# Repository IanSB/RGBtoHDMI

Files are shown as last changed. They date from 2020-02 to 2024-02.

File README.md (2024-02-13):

# RGBtoHDMI

The RGBtoHDMI interface converts the "digital" RGB video signal from
the BBC Micro or Electron to HDMI compatible with most modern
TV/Monitors. The interface comprises a Raspberry Pi Zero and a
specially designed Hat containing a small CPLD. Custom firmware on the
Raspberry Pi, in conjunction with the CPLD, is able to correctly
sample each of the Beeb's video modes to give a pixel-perfect
rendition.

For more information, see the project [Wiki](../../wiki).  
Assembled boards available here:  
https://github.com/IanSB/RGBtoHDMI/wiki/Assembled-boards-for-sale

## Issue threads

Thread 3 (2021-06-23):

amiga hoglet, software rgb/hdmi

c1581, 2021-06-23:
First time on Github, so forgive me if this is not the correct way to ask a question.

I have the rgm/hdmi adapter, commodore amiga 500, with an ACA500 plus.   Installed the adapter, on Pi0 checking for proper orientation,  software on SD card is:  20210529_777ea4f Release.

I get the "four color screen",  Amiga boots to the aca500 menu..   I get a blank screen, unless I press the spacebar, then I get a picture..  Booting, into the Amiga, screen goes blank and stays blank..   Removing the aca500 card, and just booting the amiga "plain", with 1.3 or 3.1 and again, just get a blank screen.

Is there some configuration I am missing?   I've tried it with two different Pi0's,  two different  Tv's

Thank you.

IanSB, 2021-06-28:
Which type of RGBtoHDMI board are you using?
Can you call up the RGBtoHDMI menus?

c1581, 2021-06-28:
I figured it out. I wasn’t getting any menus or anything. I soldered momentary push button on it and was able to determine it was the hertz setting. Increased from 50 to 60 and it was fine.

Thank you for getting back to me

Sean

Sent with [ProtonMail](https://protonmail.com/) Secure Email.

‐‐‐‐‐‐‐ Original Message ‐‐‐‐‐‐‐
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

Closed 2021-06-30.

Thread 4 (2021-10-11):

BOM Atari 12bit buffered pickup

md66pt, 2021-10-11:
Hi, first I want to thank you very much for your great work! I love this project and already have built one for C64 and Amiga 500.

Please let me ask you, if there is a BOM for the Atari ST 12bit unbuffered pickup board? I see two ic's and two caps at the gerbers.

I am restoring a 1040 STFM right now and would like to build one for it!

Thanks in advance, regards Wolfgang.

md66pt, 2021-10-17:
Sorry, found it in the Atari ST discussion #6!

mikrosk, 2022-03-05:
Just for future reference, he meant https://github.com/c0pperdragon/Amiga-Digital-Video/issues/6

Closed 2021-10-17.

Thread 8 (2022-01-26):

Atari MegaSTE issue

Biker1bob, 2022-01-26:
I have built one of the devices up with a 12bit board I purchased assembled - its an IanSB board.

This is the topic thread I am getting my info from https://www.atari-forum.com/viewtopic.php?t=40201

My situation is - in LOW or MEDIUM resolution - where I would use the RGB colour (AKA NOT MONO) Green is substituted for Black - I cannot get the device to produce a BLACK - It is using the STE 50hz profile. My monitor is able to do 50hz. EVERYTHING else looks fine except where a black should be there is Green.

I have adjust every setting in the software I can think of. I have rechecked all my wiring 10+ times.. I am at a loss. Any suggestions would be appreciated

I have posted this in the main Github for the project. - just thought I would post here as well incase some only follow this fork.
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

IanSB, 2022-01-28:
Addressed here:

https://github.com/hoglet67/RGBtoHDMI/issues/268

Closed 2022-01-28.

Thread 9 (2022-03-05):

Is the buffer board needed only on the Atari ST?

mikrosk, 2022-03-05:
After reading this: https://github.com/c0pperdragon/Amiga-Digital-Video/issues/6#issuecomment-766461800 and this: https://github.com/c0pperdragon/Amiga-Digital-Video/issues/56#issuecomment-933144980 it would seem that STE models do not really require this board? Not that it would be easily possible to install it (DIP vs QFP package of later Shifter models) but still it makes me wondering whether ST signal is really that bad and much improved in STE models?

IanSB, 2022-03-08:
No, the buffer board isn't needed in the STE. It isn't really needed in the ST either as you can solder directly from the 12 bit extender cable to the shifter pins but it does make fitting it easier as the upgrade is mostly plugin. I added the buffer chips to try to protect the shifter from any damage (e.g. static discharge through the cable) and they aren't really needed for signal quality reasons.

mikrosk, 2022-03-08:
Thanks. While we are on the topic, where do the three wires go?

IanSB, 2022-03-08:
They are HSYNC, VSYNC and BLANK and they are available on the Glue chip, details in the "Atari ST 40 pin shifter" section of the cables guide in the wiki:
https://github.com/IanSB/RGBtoHDMI/wiki/Cables
The H&VSYNC signals are also available on the modulator header (be careful when connecting as there is also 12V on that header) and the BLANK signal is also available on diodes around the shifter chip but the actual component numbers differ depending on the ST variant so you will need to check the schematic.

mikrosk, 2022-03-08:
Much appreciated, @IanSB.

Closed 2022-03-08.

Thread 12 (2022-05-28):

Atari STE - 9-bit adopted from STE (12-bit will come using Amiga pickup)

luciust, 2022-05-28:
Hi, thanks to @IanSB guidence - I've adopted temprorary Atari ST pickup board intended for Shifter (40-pin) to Atari STE.
The process requirer soldering and will only use 9-bits - not 12-bits, but thanks to the pickup board and bus transcievers - it makes your Atari STE safe from electrical mishaps.
Closeup of the actuall solders:

(Yellow cable is MONO)
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
HSYNC - right pin & VSYNC on left pin):
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

Results:
Mono is of course perfect:
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
Colour - it has some tint - i.e. white has cyan tint, red is a bit wahsed out, but it's far beter then expected:
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

Let me know if this need more explenation in meantime - I'm waiting for Amiga pickup that will add the 12-bit mode. Also - soldering will always be required, as the clearance for the signals pickup is HARD - my STE has PSU on top of it.

luciust, 2022-06-12:
@IanSB
So I've used the Amiga 12-bit pickup board, tested color modes:
- The HSYNC and VSYNC signals have been replaced by Composite Sync from PIN 2 of MC1377 (Color Television RGB to PAL/NTSC Encoder) which is sitting before modulator
- using your 12 bit adapter for RGB2HDMI issue 2
- Mono signal has been attached to PIN of U3 as suggested by you and the chips leg is lifted
- Beta54 FW and STE profile
- RPi Zero and Zero W (testing on two different units)

The outcome:

- in game menu - the picture is exactly *the same* as with 9-bit signals (0-2 mode) which I tested before - it's darker than original - with colors close to real output - but the colors are completly screwed (dakr green is pink and so on!) - but just during the actual game of Lotus (STE version) - blitter is running then.
- in GEM mode, the while is now white (without cyan tint) and the colors in the GEM menu are OK, but only first 8, where the next 8 are same color as 8 before. On regular monitor - the next 8 colors are lighter - which coresponds with above "darker" picture.

Other:
Minimal color artefacts are visible on some of the parts of picture,

Wondering what might be the issue?

IanSB, 2022-06-13:
First check that the sampling menu is set to 12bits per pixel with the STE profile.
Then check that the bits are in the right order
i.e. G3 on STE is connected to G3 on the Amiga pickup board, G2 <> G2, G1<> G1, G0<>G0 etc same for red & blue

IanSB, 2022-06-13:
Also need to check your soldering for shorts or unconnected pins

IanSB, 2022-06-13:
>I still haven't double-checked if my info on the R-G-B signals is correct and correctly wired - so that is still to do

That seems to be the likely cause. If the STE is anything like the ST you need to get the exact schematic for your motherboard because the different revisions of the ST all had different numbering for the resistors so using someone else's info might not work.

The grn1/VS pin will have the mono signal in mono mode but should be inactive in colour modes.

Is there a test pattern program for the STE?
On the Amiga I use the "Amiga Test Kit" and that displays ramps of RGB which makes it immediately obvious which bits are wrong:
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

luciust, 2022-06-14:
@IanSB The actual board - the MONO hack uses unused socket to meet the patch with mono signal (white cable), the purple is the CSYNC, and R G B are of course RGBs...
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

IanSB, 2022-06-14:
@luciust

>Thanks to Lopez from local Discord (greetz!) I got the gray tester.
>Look - the 1-3 or 12-bits are the same wrong. But the mode 0-2 is nearly OK, look:

That confirms that you have all the bits rotated by 1
Note that the ST (not STE) is unusual in that you connect the high source bits to R2, G2, B2 and leave R3, G3, B3 used for other things (hence "9 bits (bits 0-2)").
The STE has the more standard connections where the highest bits go to R3,G3,B3.
The STE should look correct when using "9 bits (bits 1-3)" and wrong when using "9 bits (bits 0-2)" but your results are the other way around, hence you have connected STE RGB3 to input RGB2, STE RGB2 to input RGB1 and STE RGB1 to input RGB0.
When you enable full 12 bits per pixel you get alternate dark and light stripes because STE RGB0 is connected to input RGB3 (the brightest part of the signal which alternates on/off with every bar)

So you need to rotate all your RGB connections by 1

luciust, 2022-06-14:
@IanSB
That seems to be right, and there's another issue in the C0pperDragon forum.

That also means that the STE Shifter datasheet I got is probably wrong.

Anyway, when I get back I hope to nail it finally, and when sucessfull I'll share the details in FAQ - since I've broken pretty much everything by noe, and found 4 different data on the R,G,B signals :)

Thanks for patience!

luciust, 2022-06-14:
For reference: this is the GST Shifter "datasheet" I've been checking my signals with:
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

luciust, 2022-06-15:
Finally - it works!

Based on your suggestions and pixelk0 schema - it works very well:
https://user-images.githubusercontent.com/5732483/124193866-e2011180-dac7-11eb-95ec-914855c7fa58.jpg

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

IanSB, 2022-06-15:
@luciust

Does mono mode work as well?

IanSB, 2022-06-16:
The genlock is inhibited by default in mono mode because some monitors can't lock above 60Hz and mono mode is 71 Hz. Inhibiting the genlock forces the HDMI output to 60Hz which means you should always get an image on the screen.
If your monitor can lock to 71Hz you can try changing the refresh to "Force 50Hz-Any" which should allow the HDMI output to always track the frequency of the input.
Use menu+reset to recover if this doesn't work.

luciust, 2022-06-16:
Good idea, I got two more make-SHIFT HDMI monitors - fun thing to try!

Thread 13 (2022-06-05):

Amiga 500 -colors are displayed incorrectly | black is dark red

sascha70, 2022-06-05:
Hello community,

unfortunately a bug is driving me crazy with the Amiga 500.

Unfortunately, the colors are displayed somewhat incorrectly for me. What should be black is dark red. I used the Beta54 version from JanBeta and the version from main tree 20211224_c97f06a release. All have the same problem. The adapter is from LinuxJedi (https://github.com/LinuxJedi/AmigaRGBtoHDMI/tree/main/Amiga500CPLD).

Do you have a solution?

Thanks

sascha
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
a

solarmon, 2022-06-05:
Looks like one of the red signal is missing or shorted together? I would inspect and check the soldering of the red signals and traces on the adapter itself.

Did you build the adapter yourself?

sascha70, 2022-06-05:
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

They were right. It was the plug-in lead from the Pi Zero. I checked it with a Pi 3 A+ and it worked great.

Thanks for your great project!

Greetings

Sascha

Closed 2022-12-21.

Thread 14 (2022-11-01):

Apple IIc colors inverted/wrong with Beta54

jma7x, 2022-11-01:
I just tried Beta54 with my Apple IIc (TTL interface) with a Pi 3 B, and the colors are somehow inverted/wrong.
I see the Artifact Type defaults to "Apple (Zero 2W)".  If I change it to "Simple (Old Code)", then it seems fine.
This affects both text and graphics.  (Note: I also tried Beta53 and it seemed to only have the issue with graphics)

So I guess the question is, should the new artifact color work with the Pi 3 B (from the release notes, it sounds like it?)

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

Thanks

IanSB, 2022-11-05:
@jma7x

It looks like the new artifact code can't handle the inverted video on the IIc's digital output. I don't have a IIc but I can pick up the same signals internally on the IIe so I will have a look at that when I have made up a lead.
The new code should work on the analog video output which is not inverted but would require an analog board.

jma7x, 2022-11-06:
Unfortunately I don't have an analog board, so I can't try that.  I can test any updates you make though for the digital output if that would help.
Would it be feasible to just have the cpld invert the signal?

IanSB, 2022-11-06:
@jma7x
>Would it be feasible to just have the cpld invert the signal?

No, the fix would have to be be done in software.

IanSB, 2022-11-26:
@jma7x

FYI I've just made up a lead so there should be a fix soon now that I can test it

IanSB, 2022-11-28:
@jma7x

There is a new beta 55 with a fix for Apple IIc colors here:
https://github.com/IanSB/RGBtoHDMI/releases

Let me know if it works for you

jma7x, 2022-11-29:
Looks good with beta 55!
Switching back and forth between the old code and the new, solid blocks of color seem the same, but I do see the subtle improvements on edges with the new code.
Thanks!

IanSB, 2022-11-29:
@jma7x
>Looks good with beta 55!
Switching back and forth between the old code and the new, solid blocks of color seem the same, but I do see the subtle improvements on edges with the new code.

Thanks for confirming.
The new code is mainly meant for CGA sources as it works properly in 320x200 4 colour modes and also displays the >1000 colours generated by the 8088mph demo. The old code only works in mono mode mode on CGA (i.e. similar to the Apple II) and displays a maximum of 16 colours.

Closed 2022-11-29.

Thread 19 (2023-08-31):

Alpha 60

IanSB, 2023-08-31:
Alpha 60A

Allow Apple 4 line mono to work with non-inverted video:
[Alpha60A.zip](https://github.com/IanSB/RGBtoHDMI/files/12491134/Alpha60A.zip)

IanSB, 2023-10-12:
Alpha 60B

Add Atari 2600 lumacode support
Use clock tolerance to determine lines per frame window
Fix scanlines not working on Atari 800
Some profile updates

[Alpha60B.zip](https://github.com/IanSB/RGBtoHDMI/files/12887405/Alpha60B.zip)

Closed 2023-10-14.

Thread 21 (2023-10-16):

Alpha61

IanSB, 2023-10-16:
Alpha 61A

This has a major new feature, a "Create Custom Profile" menu which makes it a lot easier to create profiles for unsupported computers.

There is some documentation on how to use it in the Info menu:

[Alpha61A.zip](https://github.com/IanSB/RGBtoHDMI/files/12922481/Alpha61A.zip)

IanSB, 2023-10-19:
Alpha 61B

Fix some issues with Profile Creation when using lumacode

Add PAL artifacts to c0pperdragon Commodore 64 YUV interface profile

[Alpha61B.zip](https://github.com/IanSB/RGBtoHDMI/files/13035203/Alpha61B.zip)

IanSB, 2023-10-19:
Alpha 61C

Add variable level scanlines to Atari 800 lumacode

[Alpha61C.zip](https://github.com/IanSB/RGBtoHDMI/files/13043471/Alpha61C.zip)

IanSB, 2023-10-22:
Alpha 61D

Updated Profile creation menu with some fixes and additional help:

[Alpha61D.zip](https://github.com/IanSB/RGBtoHDMI/files/13064442/Alpha61D.zip)

IanSB, 2023-10-26:
Alpha 61E

Add automatic detection of HDMI mode (DVI monitor or HDMI monitor)
Note the manual HDMI mode setting has now been moved to the Settings menu

Measure vsync width when calculating capture size (many Atari 2600 games have non standard vsync width)

Update Atari 2600 profile

[Alpha61E.zip](https://github.com/IanSB/RGBtoHDMI/files/13181117/Alpha61E.zip)

IanSB, 2023-11-06:
Alpha 61F

Add 4K @50/60Hz for Pi 4 (This mode is auto detected and selected on a Pi 4)
Note when connected to a 4K monitor with other Pi models, 1080p is auto detected as they can only display 4K @ 25/30Hz
You can manually select this mode if required.

Update VIC20 palette

[Alpha61F.zip](https://github.com/IanSB/RGBtoHDMI/files/13261487/Alpha61F.zip)

IanSB, 2023-11-08:
Alpha 61G
Add 'Film Mode' to drop every other frame for 25/30Hz operation
Only prevent palette dimming for brt/cont/sat/gamma/tint

[Alpha61G.zip](https://github.com/IanSB/RGBtoHDMI/files/13301831/Alpha61G.zip)

IanSB, 2023-11-09:
[kernelrpi-capturefix.zip](https://github.com/IanSB/RGBtoHDMI/files/13303587/kernelrpi-capturefix.zip)

IanSB, 2023-11-11:
[kernel_test.zip](https://github.com/IanSB/RGBtoHDMI/files/13324145/kernel_test.zip)

Closed 2023-11-12.

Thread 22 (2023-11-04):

Artifact Colors with Atari 800 Lumacode ProfIle

scorpio-ny, 2023-11-04:
Hi @IanSB ,

I have enabled artifact colors to use with some games that use color artifacts with the Atari 800 Lumacode profile. I am using the latest beta firmware. When I turn it on artifacting in the palette menu and try to set the colors be switching the angles, nothing seems to happen. Is there something else I need to do?

IanSB, 2023-11-04:
@scorpio-ny

Artifacting is not yet supported on the Atari 800.
Currently NTSC artifacting is supported on mono (e.g Apple II / Tandy CoCo) and CGA (IBM PC)
PAL artifacting is supported on 16 colour lumacode profiles such as the Commodore 64

What Atari 800 programs use artifacting?

scorpio-ny, 2023-11-05:
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

Hi @IanSB ,

Quite a few games used them since a lot of them were ports from the Apple II back in the day. Here is a partial list:
Ultima II, Ultima III & Ultima iV
Flight Simulator II
Drelbs
Pinball Contuction Set
Choplifter
LodeRunner
Snakebyte
Wavy Navy
Night Mission Pinball
Hard Hat Mack
A.E.
Threshold
Lunar Leeper
Aztec

IanSB, 2023-11-06:
@scorpio-ny

Are these games all in mono like an Apple II or do they mix the mono with other colours?

scorpio-ny, 2023-11-07:
> @scorpio-ny
>
> Are these games all in mono like an Apple II or do they mix the mono with other colours?

A little of both. Most of the examples I linked are mono like the Apple II. The Atari can also split the graphics modes on the screen  so part of the screen is mono and the rest has color. On the mono graphics modes games, the color are all generated by artifacts. What is interesting about the Atari is depending if it had the CTIA or GTIA chip or the model of Atari computer, the artifact colors it creates can be different.

Here is a link to an article on the subject that hopefully provides some useful information:
http://www.atarimania.com/faq-atari-400-800-xl-xe-what-is-artifacting_22.html

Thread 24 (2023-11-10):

NTSC Atari 800XL with PAL Antic

smarquette, 2023-11-10:
I have a NTSC Atari 800xl with a PAL Antic and I’ve installed c0pperdragon’s GTIA digitizer for HDMI output. I can make it work with an NTSC Antic and GTIA, but if I switch the Antic to PAL, I can’t find a setting that will make this work.

IanSB, 2023-11-10:
@smarquette

I assume this means you would be outputting PAL frame rate but with the timing derived from an NTSC crystal?
Does the resulting PAL timing produce colours with the NTSC palette or the PAL palette?
To support such hybrid modes would need a couple of extra profiles in the Atari folder, the settings of which depend on the above answers.

smarquette, 2023-11-10:
Yes with NTSC crystal. Color palette is NTSC and I have a Ultimate 1MB upgrade that can force the NTSC colors. I have a few newer games that need to see PAL Antic. Thanks!
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

IanSB, 2023-11-10:
@smarquette

Delete the profiles folder on the SD card and unzip then replace with this one (reboot the Pi):

[Updated_Profiles.zip](https://github.com/IanSB/RGBtoHDMI/files/13323521/Updated_Profiles.zip)

This should support the following hybrid combinations but is untested:

NTSC GTIA with NTSC crystal and PAL Antic
PAL GTIA with PAL crystal and NTSC Antic

Let me know if this works and I'll include it in the next beta due soon.

smarquette, 2023-11-10:
Thanks Ian,
I'll give it a try tomorrow.
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

smarquette, 2023-11-11:
Doesn't seem to work, I've tried all the Atari 800 lumacode profiles. Here's a picture of the screen.

Thanks
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

IanSB, 2023-11-11:
@smarquette
>Here's a picture of the screen.

Images don't seem to be included if you reply by email, I think you have to post on the github thread instead.

Can you also post a copy of the source summary page in the info menu. You can screencap this by pressing the up and down buttons (file on SD card in  /captures)

smarquette, 2023-11-11:
OK Here are the pictures:

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

IanSB, 2023-11-11:
OK it looks like the new profile will only work with the latest alpha versions so try this version:

[Alpha61H-with-new-profiles.zip](https://github.com/IanSB/RGBtoHDMI/files/13325827/Alpha61H-with-new-profiles.zip)

IanSB, 2023-11-11:
@smarquette
Do a clean reinstall of the above  by wiping the SD card and then re-select the Atari profile

smarquette, 2023-11-11:
Seems to be working.
Thanks!!!

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

IanSB, 2023-11-11:
@smarquette
>Seems to be working.

Thanks for confirming, those profiles will be in the next official beta (Beta 61) which will be released in the next day or so

A couple of questions:
What is the physical resolution and size of your monitor? (It looks similar to some 10" 1024x768 monitors I have)
In the above screenshots it shows resolution set to "Auto" but in the summary menu it shows Pi resolution set to 720x480 which is not a standard LCD resolution as far as I'm aware.

Could you use the save log.txt and EDID.bin option in the source summary menu and post those two files from your sd card.

Also do some PAL Atari games use more than 200 active lines (i.e. more active lines than an NTSC equivalent)?

smarquette, 2023-11-11:
The monitor is a 12” HD TV that can do NTSC and PAL. Since the last screenshot, I’ve changed the resolution to 1280x720 and the monitor reports it as 720p. 60hz.
If I connect my PAL C64 to my RetroTink 2x it displays as 576p.

I’ll upload those menu screen captures when I get back tomorrow morning.

As for the PAL games, I have a few, but I’m not sure of number of lines. The only game that wont run on a NTSC Antic is Bubble Shooter. The others just run at a slightly faster speed. The NTSC games all run at a slightly slower speed that is hardly perceptible.
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

IanSB, 2023-11-12:
@smarquette
I found this monitor on Ali Express:
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
Is that it? It's available in 800x600 and 1024x768 resolutions

If so you should try setting the resolution to the correct one of those two. One will look extremely sharp, the other will have softer edges.
RGBtoHDMI produces the sharpest results when set to the native physical resolution of the monitor but in that integer scaling mode some combinations of computer resolution and monitor resolution will produce larger borders. In this case 800x600 will have larger borders than 1024x768 so the latter will give the better results if your monitor is also 1024x786.

smarquette, 2023-11-12:
That looks just like it. I got it on Amazon a few years ago. I’ll give changing the resolutions a try and see if it improves.

smarquette, 2023-11-12:
Here are the log files you requested.

[logfiles.zip](https://github.com/IanSB/RGBtoHDMI/files/13328148/logfiles.zip)

This version of the monitor is actually a TV and can do up to 1920x1080 (1080p) resolution as well as standard computer resolutions.

I'd like to find a resolution/scaling setting that will fill most of the screen. Right now there is just a box in the middle with a 2-3cm border. I can use the zoom menu in the TV's menu to fill most, but it doesn't retain the setting when I turn it off.

Thanks again.

IanSB, 2023-11-12:
@smarquette
>Here are the log files you requested.

Thanks, the monitor is detected as 800x600 physical resolution so that should be the resolution selected when set to auto:
```
Timing descriptor detected as 800x600
```
Is that the case?

>This version of the monitor is actually a TV and can do up to 1920x1080 (1080p) resolution as well as standard computer resolutions.

It will probably accept a large range of resolutions and then scale them (interpolate) to fit the 800x600 screen

>I'd like to find a resolution/scaling setting that will fill most of the screen. Right now there is just a box in the middle with a 2-3cm border.

Yes, that is the problem with such a low resolution monitor, because there are so few pixels the computer resolution doesn't fit nicely into the screen resolution for integer scaling (where one computer pixel is mapped to an exact number of LCD pixels) so you end up with larger borders. This is less of a problem with higher resolution screens like 1920x1080.
See the opening page of the wiki for the difference between integer and interpolated scaling:
https://github.com/IanSB/RGBtoHDMI/wiki

To fill the screen you would have to change the scaling setting to Interpolate 4:3/Soft in the main menu and then use the crop border (zoom) setting in the preferences menu to crop off as much of the border as you prefer (use save configuration to save that setting)
When using interpolated scaling you can change the aspect ratio a little by altering  the Max Height and Max Width settings. Again use save configuration to save that setting

You may get better results by changing the scaling setting to Interpolate Full/Soft and trying all the other resolutions including widescreen ones (followed by the crop border (zoom) setting if required) as they may get squashed to fill your 4:3 screen.

BTW there is now a new beta 61 official release with the hybrid Antic support:
https://github.com/IanSB/RGBtoHDMI/releases

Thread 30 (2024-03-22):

Unable to see new profiles on the profile menu.

Finklewart, 2024-03-22:
Hi,
I've created a custom profile and can use it fine loaded as custom profile 1.
I followed the instructions on the wiki to move it to the normal profile folders and renamed it to a sensible name but whatever i do i can't get it to show up on the normal profile menu.
I'm sure I'm doing something silly.
I've got the correct 6-12_BIT_YUV_Analog folder and ive not renamed the extension from .txt
I notice a lot of the folder and file names are using _ instead of space but i tried folder and file names without spaces and that didn't work either.

Many thanks,

Jim

IanSB, 2024-03-23:
@Finklewart
What RGBtoHDMI board are you using? (i.e. main CPLD + analog board or the special lumacode/mono board)
If it's the lumacode/mono board then you need to add a trailing _ to the filename before .txt to make it show up in the profile lists. plus any new machine name folder (like Commodore / Apple etc) also has to have a trailing _

So if your machine name was Foo and the profile was Bar.txt then you need to create a folder:
/Profiles/6-12_BIT_YUV_Analog/Foo_/Bar_.txt

The reason is that both the analog board and the lumacode board share the same profile folder but only a subset of those profiles will work on the luma board so to avoid confusion profiles that don't work (i.e. without the trailing_ ) are hidden.

Leading _ is also used to change the sorting of files and folders so that special folders like Test and Custom appear at the end of the list and not in between normal manufacturers.

All the _ characters are removed or replaced by spaces in the menus so this is normally hidden from the user.

BTW what is your custom profile for?
If it's an unsupported machine perhaps you would post it here for inclusion in a future release.

Finklewart, 2024-03-23:
Hi, thank you for your reply.
It's just using the analog board, the same one as used on the ZX80/81/Apple/UK101/Ohio etc.

So for the normal analog board i don't need to worry about the trailing _ ?

The machine is a 911VDT card in a Texas Instruments TI-990 system, it has a composite video output.
Once I can get it to appear in the menu correctly i will post it.

IanSB, 2024-03-23:
@Finklewart
If it's the normal analog+cpld board pair with the 6 way IDC connector then it shouldn't need the trailing _

What is the exact path + filename you are using?

Finklewart, 2024-03-23:
Hi,
The analog board i have has a single 3.5" connector.
Is that the lumacode board ?, the person i bought it from didn't mention lumacode.
Ah, i've added the trailing _ to the path and the file name and it now shows up in the profile menu.
I had tried the _ on the file name and the folder name but i don't think on both at the same time.
Thank you very much.
I didn't see the mention of the _ in the tutorial for adding new profiles.

The file is attached, this is for the VDT911 board jumpered to 1920 characters (80x24) and 50 Hz, i will add the other 3 modes at a later date, 906 character (80 x 12 !) and both in 60 hz

Thanks for the help,

Jim

[Texas_Instruments_TI-990_VDT911_card_.zip](https://github.com/IanSB/RGBtoHDMI/files/14733354/Texas_Instruments_TI-990_VDT911_card_.zip)

IanSB, 2024-03-23:
@Finklewart
>The analog board i have has a single 3.5" connector.
>Is that the lumacode board ?

Yes. It's printed on the PCB and shown in the System Summary menu:
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

>The file is attached, this is for the VDT911 board

Thanks, it will probably appear in the "Other" folder for now.

>I will add the other 3 modes at a later date, 960 character (80 x 12 !) and both in 60 hz

It is best to create each profile individually but if the timing of these profiles is sufficiently different you can put them all in a sub-folder and RGBtoHDMI will auto select the correct one. This will certainly be the case for the 50/60 Hz ones but I don't know what difference there will be between the 80x24 and 80x12 ones. (There might not be any difference in which case both modes will work with the same profile)

See existing profiles for an example of the structure of this e.g:
/Profiles/6-12_BIT_YUV_Analog/Sinclair_/ZX81_Composite_

>I didn't see the mention of the _ in the tutorial for adding new profiles.

I haven't got around to documenting it so far. Actually, looking at the current profiles there are now a lot more uses of the _ than 'normal' profiles so it may be better to reverse the logic of this so the _ is used to signify the non-mono/luma profiles.
I might change that in a future release.

Finklewart, 2024-03-25:
Sorry for causing confusion, i'd not realised i was using the the lumacode version of the board.
Feel free to change the file and pathnames.
I think you are right, the 80 x 24 and 80 x 12 use the same screen resolution just with a lot more padding on the 80 x 12 characters.

Thanks agaon,

Jim

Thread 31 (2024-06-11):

Custom Profile (Osborne 1)

dadecoza, 2024-06-11:
I'm having an issue creating a custom profile,

According to the [Osborne 1 Technical Manual](https://www.esocop.org/docs/Osborne1TechnicalManual.pdf) the settings should be as follows ...

Width in pixels: 416
Height in pixels: 240
Dot clock: 8Mhz

However the output I get looks like ...

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

Any tips?

Thanks!

IanSB, 2024-06-12:
@dadecoza

According to the manual you linked, the actual crystal frequency is 15.9744Mhz:
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

So the "8" Mhz dot clock is 7987200 not 8000000 which might fix the mis-sampling but it looks like the image is shifted which can happen if the Hsync is wider than than the blanking period and not a normal hsync.
After tweaking the clock, can you post screencaps of the source summary page in the info menu and the geometry and sampling menus.
Press the Up and Down buttons together to screencap a menu, files in /captures on the SD card

IanSB, 2024-06-12:
@dadecoza

Looking at this further, the hsync signal is, as I suspected, not a proper hsync which usually lasts for 4.7uS and it is instead a square wave:
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
The profile is currently triggering off the edge in the middle of the screen so try changing the sync edge setting in the sampling menu which will make it trigger off the other edge.

dadecoza, 2024-06-12:
Progress!
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

Changing the edge to trailing fixed the alignment.

However it is still a little noisy.

IanSB, 2024-06-12:
@dadecoza

Have you tried adjusting the line length + or - 1, 2 or 3
(If the screen all goes noisy instead of clean on one of those settings that is probably the right value but you then have to run the calibration)

Also where have you connected the RGBtoHDMI inputs?

dadecoza, 2024-06-12:
I have tried playing with the line length but it did not help much. Not giving up though will mess around some more,

As for how it is connected ...

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

|  Osborne 1 | RGBtoHDMI |
|------------|-----------|
| VSync      | VSync     |
| HSync      | HSync     |
| Video Out  | Grn3      |
| Gnd        | Gnd       |

IanSB, 2024-06-12:
@dadecoza
The video output is really an analog signal which is at least one reason why the signal is noisy as you are feeding that into a digital input. Looking at the schematic:
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

The video is fed from a contrast control which will vary the voltage level and also the low intensity setting will reduce the voltage level too when active so characters with that attribute may appear noisy or blank.
Normally I would suggest using an analog interface addon but that can only use composite sync and in this case you can't easily combine the H and V sync signals with diodes to make composite sync because the Hsync signal is a very non-standard square wave.

It should be possible to modify an analog interface to inject separate syncs if you want to go that route but to get this working properly with the digital board you would have to connect internally to the inputs of those four open collector (O.C.) drivers shown above (Hsync, and Vsync with Grn3 and Grn2 connected to the video and intensity signals)

Turning up the contrast to max might help but the low intensity setting is still going to reduce the voltage level anyway.

dadecoza, 2024-06-12:
Hi Ian,

Thank you so much for your patience and detailed explanation.

As you probably gathered my knowledge of how video output work is very limited. At least I now have an explanation for the noise, and it really is not that bad,

Thanks again and feel free to close this ticket,

IanSB, 2024-06-12:
@dadecoza

Can you post your current profile.
Will either be in /Saved_profiles if you made any changes after creating your custom profile or if not then it will be in /Profiles

dadecoza, 2024-06-12:
[Custom_Profile_0_.txt](https://github.com/user-attachments/files/15806853/Custom_Profile_0_.txt)

as requested...

IanSB, 2024-06-12:
@dadecoza
There were some settings in your profile that needed tweaking:

As the hsync edge is so close to the active video that can cause problems so I switched from Leading to Leading+Delay (that also meant changing to 3bpp capture). Plus I set the pixel aspect ratio and the palette to mono.
It should still be possible to get this working with intensity although the connections might have to be different with a custom palette.

BTW the line length of 512 looks correct as it is a nice round binary number so all the noise is probably due to the analog signal.

Can you check that this profile is still OK and if so I will add it to future releases as it at least gets the timing correct so would be a good starting point for a fully correct profile:

[Osborne_1_(No_Intensity).txt](https://github.com/user-attachments/files/15807332/Osborne_1_.No_Intensity.txt)

Put it in this folder on the sd card:
```
\Profiles\6-12_BIT_RGB\_Other
```
reboot and select it from 'Other' in the profile menu

dadecoza, 2024-06-12:
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

Looking good!

dadecoza, 2024-06-12:
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

 Seems the intensity bit is more important than I thought ... In the above example the CP/M logo has a lower intensity and is completely absent from the RGBtoHDMI screen capture.

IanSB, 2024-06-12:
@dadecoza
>Seems the intensity bit is more important than I thought ... In the above example the CP/M logo has a lower intensity and is completely absent from the RGBtoHDMI screen capture.

There are several options to implement this:
1. Internal TTL connection
2. Use an RGBS analog addon board (some mods will be required to get the separate vsync in)
3. Use a mono/lumacode board. This is a board that contains the CPLD and part of the analog board, enough for multi level mono signals and it is mainly used with c0pperdragon's lumacode adapters to get RGBtoHDMI working with systems like the C64 / C128, Atari 800 & 2600, TI99 etc but it can be configured by using solder jumpers to input analog video and separate H and V syncs on a 3.5mm TRRS connector and that option was included for this kind of situation. (I have tried that on my Commodore PET.)
4. Use a couple of analog comparators on a breadboard between the Osborne 1 socket and the RGBtoHDMI to extract the two analog video levels. (This is effectively what the analog or mono/luma board does)

dadecoza, 2024-06-12:
Great thanks. :)

Our local vintage computing group is planning an "Osborne repair day" and I will then take the opportunity to try some of your suggestions. The repair day is also the reason I wanted to get the RGBtoHDMI working so that we can bench test/debug the main boards outside of the case.

dadecoza, 2024-06-12:
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

But man it still looks great!

dadecoza, 2024-06-12:
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
Amazing

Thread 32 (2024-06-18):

P6 on Lumacode Board?

venice1200, 2024-06-18:
This is not an issue!
I like to to know what function has P6 on the Lumacode Board.

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

Many Thanks

IanSB, 2024-06-19:
@venice1200

It's connected to the reset button for use with the hardware reset option on models other than the Pi zero.

For the Pi zero you can solder a 2 pin header on the zero board and a matching 2 pin socket in the two holes to the right of P6  (which is actually P4 on the underside) and that will allow the hardware reset option to work.

Other Pi models like the zero2W or Pi 1 to Pi 4 don't have the matching 2 pin header on the Pi board so you have to use a cable to link up from P6 to the reset input on those Pi boards (the location varies from model to model).

The lumacode board and the latest issue 7 normal CPLD board support software reset when the reset button is pressed so making the hardware reset mod is no longer essential and it's really only useful during software development to recover from crashed software when the software reset won't work.

venice1200, 2024-06-19:
Many Thanks for the information!

And all the best

Closed 2024-06-19.

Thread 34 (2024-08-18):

PAL Atari 65XE noisy video. Menu good.

sideburn, 2024-08-18:
I have a 65XE PAL and the video is noisy. Using most current firmware. Using Atari 800 lumacode (unterm) profile, and Atari 800 PAL palette.

Tried tweaking all settings I can think of but no luck.

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

video: http://sideburn.com/vid/lunacode.MOV

IanSB, 2024-09-11:
Atari noise issue answered in: https://github.com/c0pperdragon/LumaCode/issues/2#issuecomment-2295241781

Closed 2024-09-11.

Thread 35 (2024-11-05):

Atari STe - can a 12 bit extender support Mono and Colour?

shooking, 2024-11-05:
Hi there

fundamental question - should the RGBtoHDMI with 12 bit extender, suitably wired to an STe, allow low/medium colour and mono (shorting monitor 4 and 13)?

For my STFM I got it to work - had to modify profile on one system, worked with another "out of the box"

For my STe - colour worked when I chose the STe profile.
Mono - I get just a black screen, verified via screen capture, and grid lines with debug. But I see the analog out.
If I change sampling to 9 bits vsync I see signal partially getting thru

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

Hints appreciated. I am about to wire in just the 0v 5v, mono and csync as a test. BUT there seems to be a lot of debate regarding the RGB resistor ordering. See my notes at end.

Finally - would be great if WIKI showed pinout of the 16 pin male connector for the 12 bit extender.

MY SYSTEMS

So I have two types of RGBTOHDMI systems

1. RGBtoHD 12 bit issue 4 2018 - 20 Hoglet & IanB
2. RGBtoHD 12 bit issue 7 2018 - 23 Hoglet & IanB

And two 12 bit extenders

1. 12 bit adapter for RGBtoHD Issue 4 2022 IanB - struggled with STFM
2. 12 bit adapter for RGBtoHD Issue 2 2020 IanB - worked with STFM, colour STe but not mono

1. Atari STFM modified to 4Mb, CO78789
2. Atari STe CA 4003290 1989

and final part of "complication" I have

1. Pi Zero W V1.1 2017
2. Pi Zero 2 2021

WHAT WORKS

Atari ST worked with with a lot of help from Mikerochip and Javi.

I used shifter chip.
Issue 2 2020 adapter just worked.
Issue 4 2022 worked with colour. Needed help with mono
[reduce sample rate to 3bpp, modify palette to get b/w rather than yellow]
Pi choice was irrelevant (other than 1.1 allows reset)

I moved to the STe - and well things are a bit odd.

I can get colour but not mono.
Just a black screen.
Capture shows black.
Debug, show scanlines, show genlock ... displays something.
I feed the analog signal to a VGA monitor and the picture is clear.
The RGB is black BUT I modified AtariSTe Sampling to 9Bits Vsync and you can hopefully see the mono image in background. albeit geometry and position is off.

Any hints gratefully appreciated.

ONE HINT - would be nice to have a diagram of the IDC pins.
I believe they are "standard" but there is some ambiguity on the silkscreen. There is standard triangle with corresponding pin 1. But then 4 pins along there is P4. It _could_ mean ordering is Pin1 2 3 4 along long row. But seems to be normal pin 2 BELOW pin 1.
A diagram on the wiki would be cool.

I have researched and found official cable agrees with Mikerochip's hints

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

But I see other suggestions from pixelk - perhaps using an Amiga board?

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

Here's my comparison of these suggested resistors

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

And here's my photo (sorry I am red/green colour blind so I make it same as above chart BUT I am confused why there is a blu2, B2 then recommendations to change ordering due to STe R3 really being R0?
Could it be issue 4 fixes problem with issue 2 boards?

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

shooking, 2024-11-05:
I saw that thanks. I wasn't sure if the 12 bit extenders I got would work. If not (on the STe) I am OK with that - I will use MONO via VGA analog adaptor. All my monitors can handle it. I only have one monitor that could handle colour analog.

On your excellent write up I didn't understand the need to wire directly to chip. I will.re read.

I also don't understand why STFM works, but STe doesn't. I wonder if it is because the STE is using CSYNC rather than individual h and v.

luciust, 2024-11-05:
Actually - let me know which part was *not clear* - happy to change it if helps - primarly those are notes for me... So I don't have to remember it all.

CSYNC, or composite sync, can be described as a combined version of the HSYNC and VSYNC signals. Since CSYNC is defined by those two sub-components, and as you know HSYNC is horizontal sync and VSYNC is vertical sync and it is combined later for the RGBtoHDMI into CSYNC anyway. So - maybe you need to take a look at the STE profile? Show me your STE picture output and settings, maybe we will figure it out that way.

Definetly using the Amiga pickup solves any STE issues. Go for that! PCBs are very cheap today. I would send you one but it still would be more expensive than any 5 pcs from China.

shooking, 2024-11-05:
Hi and thanks.
What I am unclear about is if the 12 bit extender board I got can be modified to allow mono. My guess is the STFM version, using the level shifter and separate syncs, is doing something different to the STe.

I also see some discussion about R0 to 3 being labelled incorrectly on an STe.

I understand syncs. From what I read the STe profile knows a CSYNC will be passed in. This leaves the spare pin to interpret mono. I was hoping that the 12 bit extender I got would work in mono mode.

I will see if I can hack my setup and/or order Amiga PCB.

Thanks again

luciust, 2024-11-05:
I think it is correctly passing the MONO signal to the RGBtoHDMI sampler, but my mind is elswere now. It is hooked up to bus transciever and then... sorry - magic happens. I think the actual answer might be in my communcation couple of years back on this or on hoglet76 github, so if you can find my old posts - that would probably shed some light.

IanSB, 2024-11-05:
@shooking
>fundamental question - should the RGBtoHDMI with 12 bit extender, suitably wired to an STe, allow low/medium colour and mono (shorting monitor 4 and 13)?

Yes it should work with the mono signal fed to the Vsync input of RGBtoHDMI which is repurposed as a video input for mono mode. The mono sub profile should be auto selected when the sync signals switch to the higher refresh rate so confirm that the sub-profile shows as the mono one. (Auto selection is disabled when the menu is on screen so only call up the menu after switching)

>Hints appreciated. I am about to wire in just the 0v 5v, mono and csync as a test. BUT there seems to be a lot of debate regarding the RGB resistor ordering. See my notes at end.

The problem with bit ordering is due to the way that the STE schematic numbered the bits.

On RGBtoHDMI the bits were always R3, R2, R1, R0 ; G3, G2, G1, G0 ; B3, B2, B1, B0 with the '3' being the most significant bit  and '0' being the least significant bit.

On the ST there were only 3 bits each of RGB and they were numbered R2, R1, R0 and they could be mapped easily to the existing RGB inputs.

However on the STE an extra bit for each of RGB was added and this was the least significant bit but it was named R3, G3, B3 so the bit ordering was messed up. I presume this was so that the most significant 3 bits matched the ST but it meant that the bit order was R2, R1, R0, R3 etc.

The confusion arose from that as some users mapped them to RGBtoHDMI directly by number which messed up the bit order.
Whereas the correct order is RGBtoHDMI R3, R2, R1, R0 to STE R2, R1, R0, R3 etc.

The easiest way to avoid confusion is to go by resistor values:

The smallest value RGB resistors are connected to RGBtoHDMI R3, G3, B3
The next largest value RGB resistors are connected to RGBtoHDMI R2, G2, B2
The next largest value RGB resistors are connected to RGBtoHDMI R1, G1, B1
The largest RGB resistor values are connected to RGBtoHDMI R0, G0, B0

shooking, 2024-11-05:
Thanks @IanSB
I put diagrams based on your cable pins.
I traced the 16 pin IDC to the R0 G0 B0 etc that flow to the 12 pin header and 4 pin riser.

Did u see my partial mono image if I chose 9 bit csync?

I am wondering if the mono is generated by the low RGB. I saw your reply to @bikerbob (same as you suggested above). I originally wired according to diagram above. But I can see from the resistors values this is incorrect when compared to your explanation. It worked - as in  I got acceptable colour but I am red green colour blind :-(

Tomorrow I will solder some 90 deg header to the resistors ends and experiment with dupont cables.

Device works flawless on the STFM. Just can only get poor mono using 9 bit and vsync. Analog his res is fine. So I will wire according to resistor colours as per hints.

Thanks again for support.
Would be great to have the IDC pinout diagram  added to the wiki.

Best regards
Steve

IanSB, 2024-11-06:
@shooking
>Did u see my partial mono image if I chose 9 bit csync?

In that mode, the vsync input is used as one of the Green bits so that likely means that you have connected the mono signal to the vsync input correctly so maybe the problem is that the mono profile (which makes RGBtoHDMI look at the vsync input for video) isn't being selected properly.
Try setting Autoswich to "Off" and then manually change the sub-profile to the mono sub-profile (when the STE is in mono mode)
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
IanSB, 2024-11-08:
@shooking

Also I just noticed that you are running the latest software but your CPLD is out of date and should be 9.4
```
Running GPU capture build. Kernel version: 20240213 e630d36f
CPLD  Design: 6-12_BIT_RGB
CPLD Version: 9.2
```

Running an old CPLD with new software is not a tested combination and I think mono video on vsync is not supported in that old CPLD version so try this first:
Go into the Settings menu, then select the Update CPLD menu and program RGB v94

Do this before the tests above.
I would still be interested in the screencaps even if it now works so I can check the timings.

shooking, 2024-11-08:
@IanSB and @luciust

How can I thank you both?!!

I took a fresh 64GB card.
Formatted to fat 32
applied software - updated - I see I may have been not reading the YUV part properly
Applied 94
Copied your profiles to same directory as the official profiles
Colour - works
Mono - works!!

Here's a zip of the captures - I grabbed the log/EDID too

[TESTS.zip](https://github.com/user-attachments/files/17676156/TESTS.zip)

So what was my most likely mistake?
Having the wrong CPLD?
And thanks for everyone's help with that funky RGB.

I would ask for one more addition to the wiki please.
Something that shows the generic IDC numbering - in this case I have added the specifics for the Atari STe - but the Pin 1 with arrow (standard) coupled with the P4 (silkscreen) in 4th position made me think that perhaps the pins are numbered sequentially along long rows!

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

Anyhow - I can now do the soldering and screw the STe back together.
Great support everyone.

shooking, 2024-11-08:
We also reprogrammed all of my RGBTOHDMI to 9.4 and all works.
I think the 9.4 came out in Feb and I bought my system before then - hence why I had the mismatched CPLD.
The other system also didnt work with the STe until we updated to 9.4 - perfect

Finally - here's the colour bars you will get IF one uses the schematic R0, R1, R2, R3. My non colour blind mate helped me - but even I can see the gaps :-)

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

So all solved

luciust, 2024-11-08:
It's all about @IanSB way of doing things - he's has a great way of helping here with perfect results, I could say the same thing when I first looked at the project: how can I thank him! So, inspired by his work I took extra step to document my strugle.
And I'm so glad that another STE is fitted with RGBtoHDMI, as the new racer game is comming!

IanSB, 2024-11-08:
@shooking
>Applied 94
>So what was my most likely mistake?
>Having the wrong CPLD?

The mono issue was just the wrong CPLD. The software should auto prompt to update the CPLD on a fresh install but there was a bug introduced some time ago that stopped that from working. That has now been fixed for the next release.

>Here's a zip of the captures - I grabbed the log/EDID too

Those timings look fine so I guess the standard Atari STE profile should work OK

>Anyhow - I can now do the soldering and screw the STe back together.

Glad you got it sorted out.

shooking, 2024-11-10:
closing as YES Atari STe works with 12 bit extender provided correct CPLD and wiring is used.
Excellent work all involved.

IanSB, 2024-11-10:
@shooking
FYI I updated the cables sections of the wiki showing some photos of my Atari STFM installation including use of a detachable cable

Closed 2024-11-10.

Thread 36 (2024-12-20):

Amiga A2024 format?

reinauer, 2024-12-20:
Hi,

is it feasible to implement the A2024 monitor support on RGB2HDMI?

IanSB, 2024-12-21:
@reinauer
It might be possible but I don't have any hardware to do any tests with.
Do you have any tech info on the resolution, refresh rate, sync type, video levels/bits per pixel etc?

MrSVCD, 2025-04-18:
I would also like A2024 mode.
Here is some resources that I found:
The patent that it is based on: https://patentimages.storage.googleapis.com/48/cd/38/ecc974a1db5c37/US4851826.pdf
Hedley Davis (Designer of A2024) on the A2024:s greyscale: https://forum.amiga.org/index.php?topic=73629.0
A add-in card for A2000,A3000 and A4000 that does the same thing as A2024 but with a different monitor: https://amiga.resource.cx/exp/moniterm

MrSVCD, 2025-04-18:
I did some test in a AmiBerry and recorded a A500 OCS in A2024 mode and notised that the settings for which mode is used and which part of the screen is uppdated is transferred in the top overscan bit of the video signal.
[10Hz-mode.zip](https://github.com/user-attachments/files/19816738/10Hz-mode.zip)
[15Hz-mode.zip](https://github.com/user-attachments/files/19816739/15Hz-mode.zip)

IanSB, 2025-04-19:
@MrSVCD
>I recorded a A500 OCS in A2024 mode

How do you put an A500 OCS into A2024 mode?

It seems it should be possible to get this working, the only potential problem I can see is that the higher memory bandwidth required for the Hi res screen might interfere with video capture.

I might look at this once I have finished HDMI audio support.

MrSVCD, 2025-04-19:
What you see in the pictures are the test image from AmigaOS 3.2 and in that and I think from version 2.x you can just move the A2024 monitor definition files from storage in to devs.
On a Kickstart 1.3 machine you need a "A2024 Monitor Setup 'Jumpstart' Disk": [A2024 Monitor Setup 'Jumpstart' Disk.zip](https://github.com/user-attachments/files/19821733/A2024.Monitor.Setup.Jumpstart.Disk.zip)
Since I don't have a A2024 to test with I am not sure that it works but in Amiberry it does flicker almost the same way that AmigaOS 3.2 does.

MrSVCD, 2025-04-19:
> It seems it should be possible to get this working, the only potential problem I can see is that the higher memory bandwidth required for the Hi res screen might interfere with video capture.

I think it does use the same bandwidth as the normal signal since it is buffering the each fourth/sixth of the screen and just updates the part that is sent at that moment.
In NTSC land:
The 10Hz mode splits the screen into 6 parts and updates each part 10 times a second, 6 parts * 10 times a second = 60Hz.
15Hz mode does the same but 4 parts and 15 times a second.
(If you try to watch video it would be screen tearing galore.)

In PAL land it is 50Hz divided by 6 (8⅓Hz) and 4 (12½Hz) instead.

MrSVCD, 2025-04-19:
[WB1.3 Jumpstart.zip](https://github.com/user-attachments/files/19822785/WB1.3.Jumpstart.zip) - Amiberry output of the Jumpstart floppy on KS1.3 rom.

Notes on the resolutions:
On OCS hardware with Angus the horizontal resolution is 1008 pixels, On hardware that has Fat Angus or newer the horizontal resolution is 1024 pixels.

On a PAL machine the vertical resolution is 1024 lines and on a NTSC machine it is 800 lines.
This corresponds to the maximum vertical resolution of the interlaced standard modes *2.

IanSB, 2025-04-20:
@MrSVCD

Looking at your screencaps of the individual screens, they both seem to be displaying 1008x1024 so why are there two different ways of sending the same resolution with 4 frames and 6 frames using (I presume) 504x256 and 336x256 respectively?

Also do you know how the Amiga's 12 bit RRRRGGGGBBBB digital output which is captured by RGBtoHDMI maps to the RGBI digital output of the video hybrid?

MrSVCD, 2025-04-20:
> Looking at your screencaps of the individual screens, they both seem to be displaying 1008x1024 so why are there two different ways of sending the same resolution with 4 frames and 6 frames using (I presume) 504x256 and 336x256 respectively?

The 6 frame mode uses less bandwidth than the 4 frame mode.
This according to the manual [https://www.retro-commodore.eu/monitors/](https://www.retro-commodore.eu/monitors/) "A2024 High Resolution Monitor User's Guide"
Just the English part: [Commodore_A2024_High_Resolution_Monitor_Users_Guide-English.zip](https://github.com/user-attachments/files/19825019/Commodore_A2024_High_Resolution_Monitor_Users_Guide-English.zip)

> Also do you know how the Amiga's 12 bit RRRRGGGGBBBB digital output which is captured by RGBtoHDMI maps to the RGBI digital output of the video hybrid?

The signal for RGBI is taken (almost) direct from Denise so the adapter-boards have access to them already.
```
DR = R(3)
DG = G(3)
DB = B(3)
DI = B(0)
```
This is according to the schematics available here: [https://amigawiki.org/doku.php?id=en:service:schematics](https://amigawiki.org/doku.php?id=en:service:schematics)
It is a bit hard to see on the A500 schematic but there is a dot on the lines used by RGBI right next to the Video Hybrid to show that the lines on the right is connected under the HY1 IC to the DB23.

IanSB, 2025-04-20:
@MrSVCD
>Notes on the resolutions:
On OCS hardware with Angus the horizontal resolution is 1008 pixels, On hardware that has Fat Angus or newer the horizontal resolution is 1024 pixels.

In 1008 pixel mode the horizontal resolutions are 504 for 4 frame mode and 336 for 6 frame mode
How does the horizontal resolution of 1024 work?
In 4 frame mode it would be 512 pixels per frame but what about 6 frame mode as 1024 is not divisible by 3?

MrSVCD, 2025-04-22:
More pictures from  Amiberry with a test pattern for width:
[10Hz Fat test.zip](https://github.com/user-attachments/files/19853641/10Hz.Fat.test.zip)
[10Hz OCS test.zip](https://github.com/user-attachments/files/19853644/10Hz.OCS.test.zip)
[15Hz Fat test.zip](https://github.com/user-attachments/files/19853643/15Hz.Fat.test.zip)
[15Hz OCS test.zip](https://github.com/user-attachments/files/19853642/15Hz.OCS.test.zip)
(The OCS version had some graphics glitches for some reason.)

It seems that 6 frame mode is 352 pixels wide that overlaps with 16 pixels, so if you put the pictures side by side without overlap it is 1024+32=1056 pixels.
This seems to be true for both OCS and Fat Angus, just that for some reason the OCS version repeats the first 16 pixels from the previous line in its last 16 so the monitor just cuts them off.

The 4 frame mode is always 512 pixels wide and OCS Angus again has the same bug here.

MrSVCD, 2025-04-22:
Here are the first couple of lines that a PAL Amiga 500 uses to communicate with a A2024:
Fat Angus:
  10Hz 1-bit
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
  10Hz 2-bits
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
  15Hz 1-bit
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
  15Hz 2-bits
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
OCS Angus:
  10Hz 1-bit
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
  10Hz 2-bits
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
  15Hz 1-bit
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
  15Hz 2-bits
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

The first lines are red and I think that is a sign that extended resolution/A2024 mode signal is sent.
The line with different colours is where different settings are sent:

1. The longer part in the beginning of the line is to set 10Hz (Red) or 15Hz (Black)
2. First short field is which frame that is updated: 0=Black 1=Red 2=Green 3=Yellow 4=Blue 5=Purple
3. The second short field is always yellow on a PAL Amiga 500
4. The third short field is bit depth and if it should crop the last 16 pixels horizontally:
- Red indicates bit depth: Off is 1-bit and On is 2-bits
- Green is always On on a PAL Amiga 500
- Blue indicates if cropping is needed: Off disables cropping and On enables it.

**Note:** I can not visually see if the Intensity bit is set since it is the least significant bit of blue.

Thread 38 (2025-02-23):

Beta65 NES graphic errors

mvbhz, 2025-02-23:
I downloaded Beta 65 (Beta65.zip Dec 30, 2024) release to use it on NES (PPUDigitizer & RGB2HDMI). Unfortunately I get graphical errors:

https://ibb.co/356dM3pf

Also the aspect ratio is not preserved - the image is stretched horizontally.

I select the "NES Lumacode" profile. How to fix this?)

IanSB, 2025-02-23:
@mvbhz
What type and issue number of RGBtoHDMI are you using
e.g. standard CPLD + analog RGB or mono/lumcode board and issue 3, 4 or 5 etc
Are you using the standard or unterminated (unterm) version of the profile. Try the latter if not using it.

mvbhz, 2025-02-23:
I use PPUDigitizer by C0pperdragon + RGBtoHDMI Mono & LumaCode + RBPi0. After switching to RGB profile (Unterm) there are no graphic errors, but there is still aspect ratio 16:9 instead of 4:3.

IanSB, 2025-02-23:
@mvbhz
What resolution monitor are you using and what are the settings for Resolution & Scaling in the main menu?

Can you post a screencap of the source summary menu (in the info menu)
Press the up and down buttons when in that menu and the screencap will be in /captures on the SD card
Also use the save log and edid option in the info menu and post log.txt from the SD card

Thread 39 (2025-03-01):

NES Lumacode - Missing Green? Emphasis

AWalGH, 2025-03-01:
Using an (NTSC) Sharp Twin Famicom with a 2C02E. I recently installed c0pperdragon's fantastic PPU digitizer and performed a clean install on the mSD card for my RGBtoHDMI to software Beta65 as made available here on the releases page.

The picture is fantastic, and significantly more stable than some other solutions I've tried.

On a whim I decided to try one of the palette testing roms one can get on the internet, but I've unfortunately discovered that (I believe) the green emphasis bit ($2001 Bit 6 (Counting 7-0)) is being ignored.

[Palette Test ROM Available Here](https://forums.nesdev.org/viewtopic.php?t=13264)

Example screengrabs from a capture card in order to grab the composite output as well.

Composite - No emphasis bits:
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
Composite - Emphasize blue:
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
Composite - Emphasize green:
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
Composite - Emphasize red:
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

RGBtoHDMI - No emphasis bits:
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
RGBtoHDMI - Emphasize blue:
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
RGBtoHDMI - Emphasize green (This is our failure state. The output is the same as No emphasis bits):
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
RGBtoHDMI - Emphasize red:
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

Do note that green and red emphasis are on opposite bits on PAL (2C07) PPUs.
I do not own any PAL PPUs therefore I cannot test to see if there is any issues with them, sorry.

If you need any further information for troubleshooting please let me know. Thank you.

IanSB, 2025-03-24:
@AWalGH

This is a known issue and will be addressed in a future update.

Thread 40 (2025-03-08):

Beta65 cycling

otacon6530, 2025-03-08:
I am using PPUDigitizer by C0pperdragon + RGBtoHDMI Mono & LumaCode + RBPI400.

It is loading to the color test with 4 squares then all lights go out on the RGBtoHDMI and the screen goes black for a few seconds and then the behavior repeats forever.

Using the latest official release works just fine, except that the nes PPUdigitizer profile doesn't exist of course. Though I do enjoy coco vision via the PPUDigitizer. It has a pleasant if not authentic feel.

IanSB, 2025-03-24:
@otacon6530

When it goes into a boot loop like that it usually means it can't detect the HDMI monitor but it will reboot once or twice if it needs to change some configuration and if that isn't working for some reason it might continually boot.

Try a clean install on a new SD card.

To find out what is going on you could connect a TTL USB serial cable to the TxD and GnD pins marked on the 40 way header then view the boot log using a serial terminal program 115200 baud 8 data no parity.

otacon6530, 2025-04-14:
@IanSB The 400 has two HDMI outputs, so I wonder If I just need to switch to the other one or disable the second somehow, so the software doesn't get confused.. I moved the SD card to a raspberry pi 3 for now and it works, so I am less worried about getting the clunky 400 working at this point.

IanSB, 2025-05-20:
@otacon6530

It looks like the current betas are not working on the Pi 4 due to hardware differences so it may take some time to investigate that.

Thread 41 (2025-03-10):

Single Button Mode?

thesnable, 2025-03-10:
Hello!

I have a board with one Button only.. i cannot find a way to enable single button mode... it isnt written.. or i cant find it.

Thanks alot!

thesnable, 2025-03-10:
Found it .. its with the files in a subdir .. thanks :D

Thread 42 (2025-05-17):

Beta66 - audio add-on board

solarmon, 2025-05-17:
Hi,

Thank you so much for the audio injection feature in RGBtoHDMI!

Not sure if this is the right channel to ask this question, but are there any plans to release the audio add-on board schematics and/or board design file?

Or a way to reduce the price of the boards for bulk purchase?

As a designer and builder of the RGBtoHDMI CDTV v2 beards, I get asked/requested a lot about audio injection into HDMI. It would be great if I can optionally supply these boards with audio injection integration already done so that users/buyers don't need to do it themselves.

My RGBtoHDMI CDTV v2 boards have the audio signals already presented, so integration is certainly easier:

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

Thank you!

IanSB, 2025-05-19:
@solarmon
>are there any plans to release the audio add-on board schematics and/or board design file?

I am looking at at the possibility of releasing an easier to build design for DIY assembly using larger packages at some point in the future but it would be under a no commercial use licence.

At the moment I'm trying to raise some funds to continue this project as it is very expensive to maintain. (I just spent another £1000 over the past few weeks buying additional vintage computers and associated parts just to add support for them). The sellers listed in the wiki provide donations from their sales including the audio board but there are many others sellers that don't provide any financial support. (I haven't had any financial support from any Amiga sellers)

>Or a way to reduce the price of the boards for bulk purchase?

That should be possible, do you have a contact email address?

solarmon, 2025-05-19:
@IanSB

Please use the email in my user profile.

Thank you for your magnificent work on this project. I have in the past given a donation to c0pperdragon from sales of my boards based on their original RGBtoHDMI board for the Amiga. I'd be happy to contribute for your efforts too.

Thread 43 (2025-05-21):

Alpha 67

IanSB, 2025-05-21:
Alpha 67A test
Changes:
Add Audio mode option for mono mixdown of stereo audio
Add boot log dump if menu button held down
Improve detection code for audio board.

[Alpha67A.zip](https://github.com/user-attachments/files/20358720/Alpha67A.zip)

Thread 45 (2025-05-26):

Audio Issue on CDTV with Audio Addon Board

braykout, 2025-05-26:
I installed the Audio Add-on Board in a CDTV. The CD audio sounds fine, but the Paula audio has too high a volume, sounds clipped, and is noisy. I don't want to rule out the possibility that it's my CDTV. Has anyone tested it on a CDTV? The audio is taken from the video out port, and the CD audio and Paula audio appear to be mixed there beforehand. I tested it with Beta66.

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

IanSB, 2025-05-26:
@braykout
@solarmon

I don't have one myself but the board designer solarmon has tried it so he might be able to help you.
The A to D chip has a maximum input voltage range of 3 volts peak to peak so if you have an oscilloscope you could check the voltage level of the audio. If it exceeds that limit you will have to reduce it with resistors or pick up the audio at a different point.

I am working on a software volume level adjustment to increase or decrease the audio level on the HDMI output but that is mainly to allow the audio level to be adjusted to match other audio sources. That won't help if the input audio level exceeds the maximum 3v p-p.

IanSB, 2025-05-26:
@braykout
>By the way, the Paula sound isn't clipping through the headphone output.

Have you tried connecting the headphone output to the audio card?

>I might try installing a resistor between the audio source and the audio board

To reduce the volume you might have to make up a potential divider using two resistors in series for each channel.
i.e. solder two resistors such as 1K each in series from the audio output to ground and connect the audio card to the middle of the resistors. This would reduce the audio level by half. (do the same for both left and right channels)

ChadsArcade, 2025-07-01:
So I have a bit of an update... I also own an Amiga 500 also equipped with RGB2HDMI and the audio board. My aim was to attempt to find a resistor pair to make the CDTV sound the same as the A500. This was done fairly un-scientifically - just by ear.

The reference machine is an A500 with RGB2HDMI + Audio running Superfrog, TV volume is set to 10

The CDTV was fitted with various potential divider values and was also running Superfrog on the same TV. Comparisons were made by ear when flipping between the HDMI inputs of the A500 and CDTV.

CDTV potential divider tests:
10k - 10k resistors - audio not clipped but very loud. Setting the TV volume to about 5 makes it match the A500
2k2 - 1k resistors - not as loud, setting TV volume to about 7 makes it match the A500

I was going to test 3k3 - 1k next, then I remembered the above image of the modded CDTV board, so:

4k7 - 1k resistors - just about right. Setting TV to 9 is about the same as the A500, maybe slightly softer. Volume at 10 is only slightly louder to my ear.

Maybe the next preferred value would match the A500... maybe it would overshoot. It's close enough for me - people are not going to be comparing two machines side by side this way as I have done. Plus there will be a software setting to adjust the level in future.

A voltage divider with these values would set the output at 0.877 assuming 5v peak. Audio from the A500 is tapped from the phono outputs which I assume are line level...? I.m hoping whoever modded the CDTV board above made the appropriate measurements and calculations to come up with 4k7 - 1k.

So to summarise:
Audio signal from CDTV ----| 4k7 |------+-------| 1k |------ Gnd

Tap the signal from the centre of the two resistors, and it sounds about the same as an A500 equipped with RGB2HDMI.

Ta!

Closed 2025-08-07.

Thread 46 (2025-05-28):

NES Lumacode Scanlines Not Working

k6lcm, 2025-05-28:
When using the Lumacode output from the PPUDigitizer in an original Nintendo Entertainment System (NES) as a video input source to the RGBtoHDMI Mono board, the option to enable scanlines for CRT simulation is available in the menu but does not produce any visual change to the video when enabled.

IanSB, 2025-05-29:
@k6lcm

Yes, looks like that's a bug. It should be fixed on the next release.

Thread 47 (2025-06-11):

Release sources for boards based on older revisions per GPL v3 license.

raymondh2, 2025-06-11:
Some of the later board revisions (PC buffer) do not have their sources released. This is a violation of the GPL v3 license the previous revisions were based on

IanSB, 2025-06-12:
@raymondh2
>Some of the later board revisions (PC buffer) do not have their sources released

I have dual licensed my original designs such as the above and the revised versions of those designs are for commercial use.
They are basically the same but have changes to make automated assembly easier and add some signal protection.

Closed 2025-06-12.

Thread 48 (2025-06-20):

Audio output not detected on Extron IN1608 xi when tring HDMI audio release(s)

AWalGH, 2025-06-20:
Pretty much as is says on the tin. I can confirm that the audio capture boards I've soldered on myself as well ones I have received recently as that were purchased as part of a set all appear to be working just fine for mono audio (It's all I configured them for), but I cannot for the life of me get any of these devices to output HDMI audio to my Extron IN1608 xi  "Presentation Switcher" I use to select and split HDMI between devices (One In From a Choice of Five+Three, Two+One Out).

If I connect the devices directly to one of a few monitors/TVs I have available the RGBtoHDMI devices with one of the newer firmware options all can send audio over HDMI without issue. I also have an ezcap401 that appears to work with the audio output if I connect it directly.

Alpha65G, Beta66 and Alpha67A all appear to produce the same results.

The 1608 has a sub-menu for tweaking audio options since it can mix microphones and other sources, but the menu reports to me that it doesn't detect any audio from the HDMI source when I select one with an RGBtoHDMI.

IanSB, 2025-06-20:
My guess is that the auto detection is getting messed up when connected to the Extron.
Can you use the save log and edid option in the info menu (when connected to the problem switcher) and post Log.txt and EDID.bin from the SD card.

AWalGH, 2025-06-21:
> Can you use the save log and edid option in the info menu (when connected to the problem switcher) and post Log.txt and EDID.bin from the SD card.

Sure thing

[Log.txt](https://github.com/user-attachments/files/20845260/Log.txt)

[EDID.BIN (PixelDrain)](https://pixeldrain.com/u/pXWcHhhB)

IanSB, 2025-06-21:
There doesn't seem to be anything wrong in the logs and I programmed your EDID into an EDID emulator which is connected inbetween a Pi zero and a monitor so that the zero used that EDID info to setup everything and the audio on the monitor still worked so it doesn't look like anything in the EDID is causing the problem.

The only remaining thing I can think of that might cause a problem is an issue with the IEC958 bitstream formatting. Each audio sample is 24 bits and the remaining 8 bits are used to pass some metadata like packet start, sample rate, number of channels, parity bit etc. A lot of TVs seem to ignore this as they work even if all that is missing but some do require it to be present in some form.
Maybe the switcher is very strict about this metadata and if something is slightly wrong then it just ignores the audio. I guess it must be using that data in order to manipulate the audio like mixing in other sources.

Is there any difference when playing the test WAVs or test tone as that uses different code to generate that metadata?

AWalGH, 2025-06-22:
> Is there any difference when playing the test WAVs or test tone as that uses different code to generate that metadata?

Unfortunately no; It still detects no audio from the HDMI.
I've also tried disconnecting the HDMI cable from the RGBtoHDMI device then re-connecting it while it's playing one of the test sounds with no change.

IanSB, 2025-06-22:
Can you try this firmware:

[kernelrpi.zip](https://github.com/user-attachments/files/20853190/kernelrpi.zip)

Put Beta66 or Alpha67A on the SD card.
Unzip the above to get Kernelrpi.img and overwrite the same file on the SD card then reboot.

This changes the frame preamble bits to match the linux driver.

Try both the WAV player and the audio capture.

AWalGH, 2025-06-22:
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

The new kernel file loads just fine and is recognized as such in the info menu, unfortunately there does not appear to be any difference in the way it's detected and the scaler still shows no audio from the RGBtoHDMI, regardless of mode. Unplugging and replugging while the device is playing a test file or tone didn't make any difference either.

Just like with the previous firmwares, plugging the device directly into literally any other device I happen to have nearby appears tp work just fine. The audio can also be stopped, changed and toggled as well without any fuss on these other things.

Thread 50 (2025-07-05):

Amiga 600 audio

kirkegaard, 2025-07-05:
Im struggling a bit trying to figure out how to pick up stereo signal from my A600. Analogue audio was never my thing :)
If i understand correctly the RCA has a switch that needs to be shorted to switch from mono to stereo. So do i solder the signal pads to left and right, and ground to the shortbar and then the two short as soon as i connect the jack to the hdmi audio board? Or does ground go to the ground pins on the RCA?

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

kirkegaard, 2025-07-05:
I just found this and i think ive figured it out. R334 and R324 seems to be a good place. Or negative side of the caps on the front side of the board, although i think everybody knows how hard that is :D

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

IanSB, 2025-07-06:
I don't have an A600 so have not tried this but I understand that you connect the left and right audio to the centre pins of the left and right audio outputs which might only be accessible from the underside of the PCB then insert unconnected RCA/Phono connectors into both outputs which will cause the switches that short the left and right outputs together to be opened.

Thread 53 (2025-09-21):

Inverted Video on Color Computer 2 After Sound Daughterboard Installation

yocummr, 2025-09-21:
Greetings,

I installed the RGB2HDMI board on my Color Computer 2 earlier in the week. It works very well, and I am very pleased with it.

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

I also ordered the sound daughterboard and installed it last night. The sound works also, however when it’s installed, my Color Computer 2 inverts the video, like so:

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

I uninstalled the daughterboard, and the video went back to normal. To verify, I reinstalled the daughterboard and got the same result: sound and inverted video.

Do you have any ideas on what might be wrong here (operator error)?

Thank you,
Mike Yocum
Washington IL

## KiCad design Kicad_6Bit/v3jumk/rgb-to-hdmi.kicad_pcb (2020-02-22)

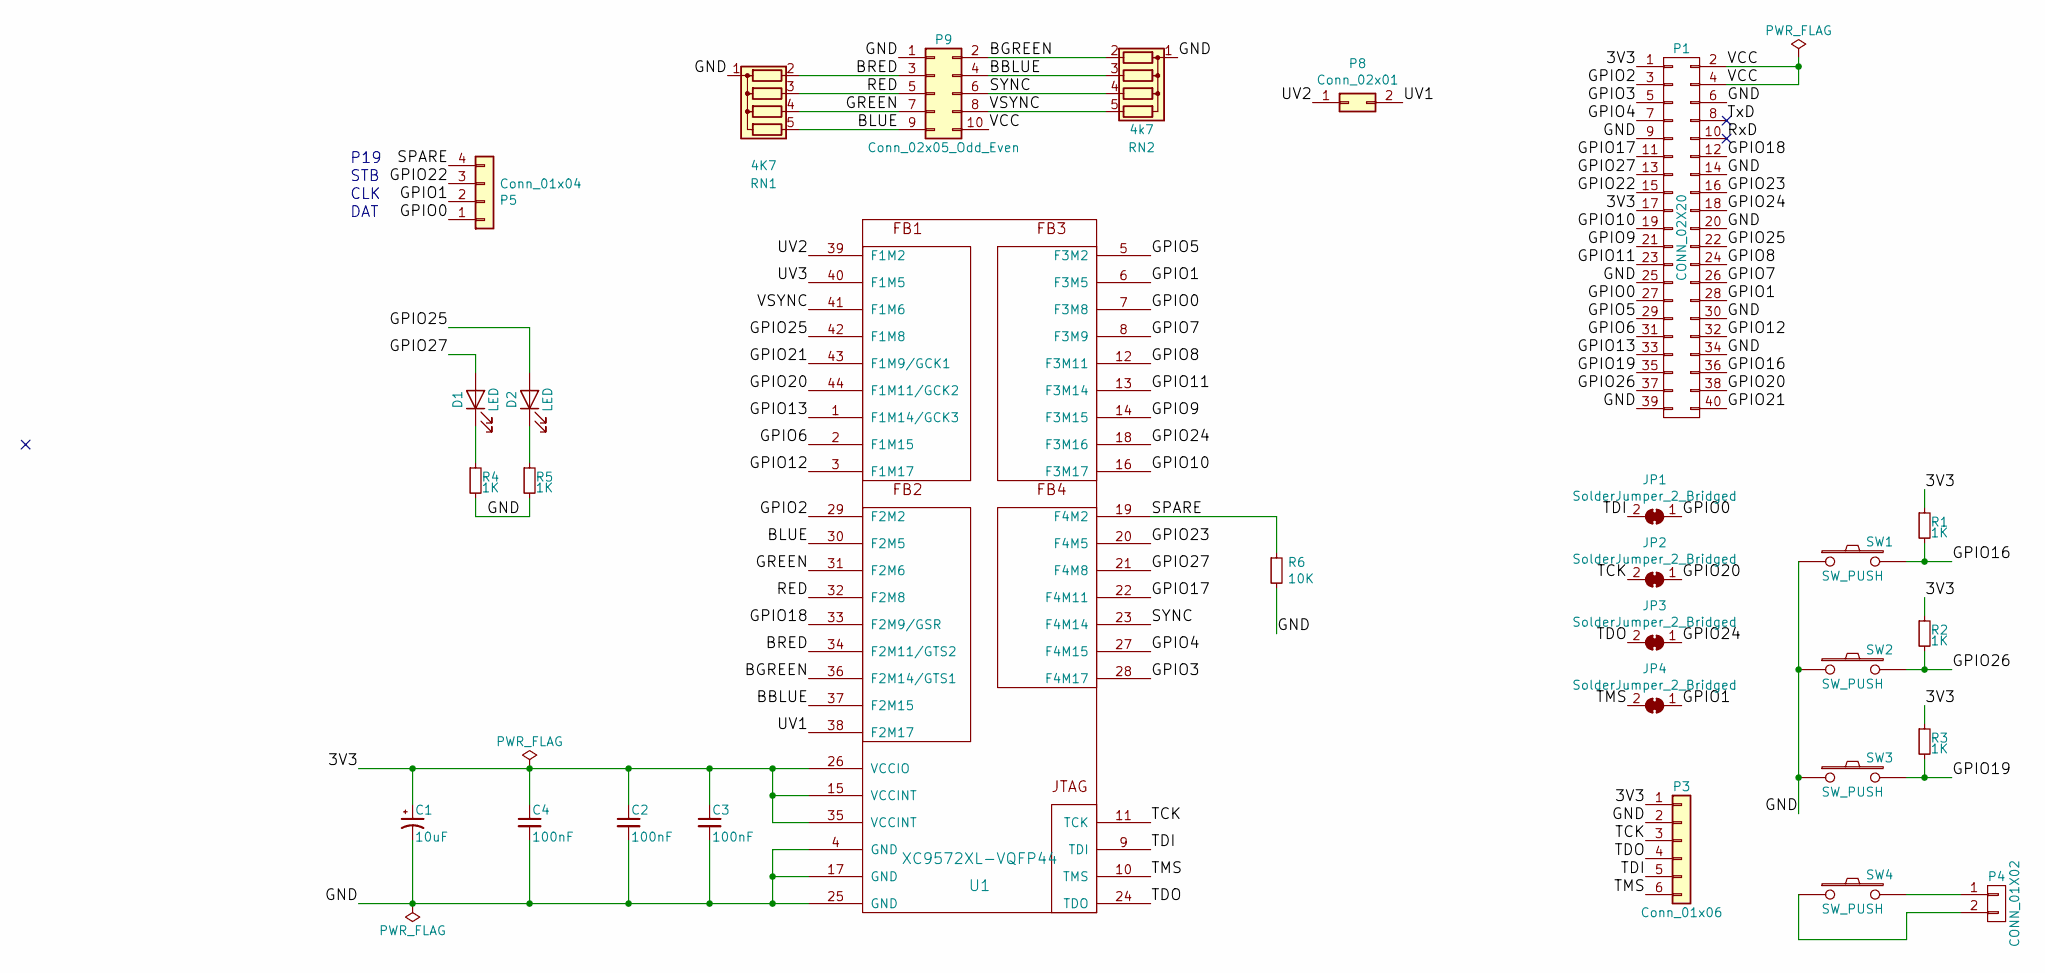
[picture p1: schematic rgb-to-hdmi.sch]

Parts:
C1: 10uF; C_0805_2012Metric_Pad1.15x1.40mm_HandSolder
C2, C3, C4: 100nF; C_0805_2012Metric_Pad1.15x1.40mm_HandSolder
D1, D2: LED; LED_D1.8mm_W3.3mm_H2.4mm
JP1, JP2, JP3, JP4: SolderJumper_2_Bridged; SolderJumper-2_P1.3mm_Bridged_RoundedPad1.0x1.5mm
P1: CONN_02X20; PinSocket_2x20_P2.54mm_Vertical
P3: Conn_01x06; PinHeader_1x06_P2.54mm_Vertical
P4: CONN_01X02; PinSocket_1x02_P2.54mm_Vertical
P5: Conn_01x04; PinSocket_1x04_P2.54mm_Vertical
P8: Conn_02x01; PinHeader_2x01_P2.54mm_Horizontal
P9: Conn_02x05_Odd_Even; PinHeader_2x05_P2.54mm_Horizontal
R1, R2, R3, R4, R5: 1K; R_0805_2012Metric_Pad1.15x1.40mm_HandSolder
R6: 10K; R_0805_2012Metric_Pad1.15x1.40mm_HandSolder
RN1: 4K7; R_Array_SIP5
RN2: 4k7; R_Array_SIP5
SW1, SW2, SW3, SW4: SW_PUSH; SW_PUSH_6mm_H5mm
U1: XC9572XL-VQFP44; LQFP-44_10x10mm_P0.8mm

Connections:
/3V3: C1.1, C2.1, C3.1, C4.1, P1.1, P1.17, P3.1, R1.1, R2.1, R3.1, U1.15 (VCCINT), U1.26 (VCCIO), U1.35 (VCCINT)
/BBLUE: P9.4, RN2.3 (R2), U1.37 (F2M15)
/BGREEN: P9.2, RN2.2 (R1), U1.36 (F2M14/GTS1)
/BLUE: P9.9, RN1.5 (R4), U1.30 (F2M5)
/BRED: P9.3, RN1.2 (R1), U1.34 (F2M11/GTS2)
/GND: C1.2, C2.2, C3.2, C4.2, P1.6, P1.9, P1.14, P1.20, P1.25, P1.30, P1.34, P1.39, P3.2, P9.1, R4.2, R5.2, R6.2, RN1.1 (common), RN2.1 (common), SW1.1, SW2.1, SW3.1, U1.4 (GND), U1.17 (GND), U1.25 (GND)
/GPIO0: JP1.1 (A), P1.27, P5.1, U1.7 (F3M8)
/GPIO1: JP4.1 (A), P1.28, P5.2, U1.6 (F3M5)
/GPIO2: P1.3, U1.29 (F2M2)
/GPIO3: P1.5, U1.28 (F4M17)
/GPIO4: P1.7, U1.27 (F4M15)
/GPIO5: P1.29, U1.5 (F3M2)
/GPIO6: P1.31, U1.2 (F1M15)
/GPIO7: P1.26, U1.8 (F3M9)
/GPIO8: P1.24, U1.12 (F3M11)
/GPIO9: P1.21, U1.14 (F3M15)
/GPIO10: P1.19, U1.16 (F3M17)
/GPIO11: P1.23, U1.13 (F3M14)
/GPIO12: P1.32, U1.3 (F1M17)
/GPIO13: P1.33, U1.1 (F1M14/GCK3)
/GPIO16: P1.36, R1.2, SW1.2
/GPIO17: P1.11, U1.22 (F4M11)
/GPIO18: P1.12, U1.33 (F2M9/GSR)
/GPIO19: P1.35, R3.2, SW3.2
/GPIO20: JP2.1 (A), P1.38, U1.44 (F1M11/GCK2)
/GPIO21: P1.40, U1.43 (F1M9/GCK1)
/GPIO22: P1.15, P5.3
/GPIO23: P1.16, U1.20 (F4M5)
/GPIO24: JP3.1 (A), P1.18, U1.18 (F3M16)
/GPIO25: D2.2 (A), P1.22, U1.42 (F1M8)
/GPIO26: P1.37, R2.2, SW2.2
/GPIO27: D1.2 (A), P1.13, U1.21 (F4M8)
/GREEN: P9.7, RN1.4 (R3), U1.31 (F2M6)
/RED: P9.5, RN1.3 (R2), U1.32 (F2M8)
/RxD: P1.10
/SPARE: P5.4, R6.1, U1.19 (F4M2)
/SYNC: P9.6, RN2.4 (R3), U1.23 (F4M14)
/TCK: JP2.2 (B), P3.3, U1.11 (TCK)
/TDI: JP1.2 (B), P3.5, U1.9 (TDI)
/TDO: JP3.2 (B), P3.4, U1.24 (TDO)
/TMS: JP4.2 (B), P3.6, U1.10 (TMS)
/TxD: P1.8
/UV1: P8.2, U1.38 (F2M17)
/UV2: P8.1, U1.39 (F1M2)
/UV3: U1.40 (F1M5)
/VCC: P1.2, P1.4, P9.10
/VSYNC: P9.8, RN2.5 (R4), U1.41 (F1M6)
unnamed: D1.1 (K), R4.1
unnamed: D2.1 (K), R5.1
unnamed: P4.1, SW4.2
unnamed: P4.2, SW4.1

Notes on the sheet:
DAT
CLK
STB
P19

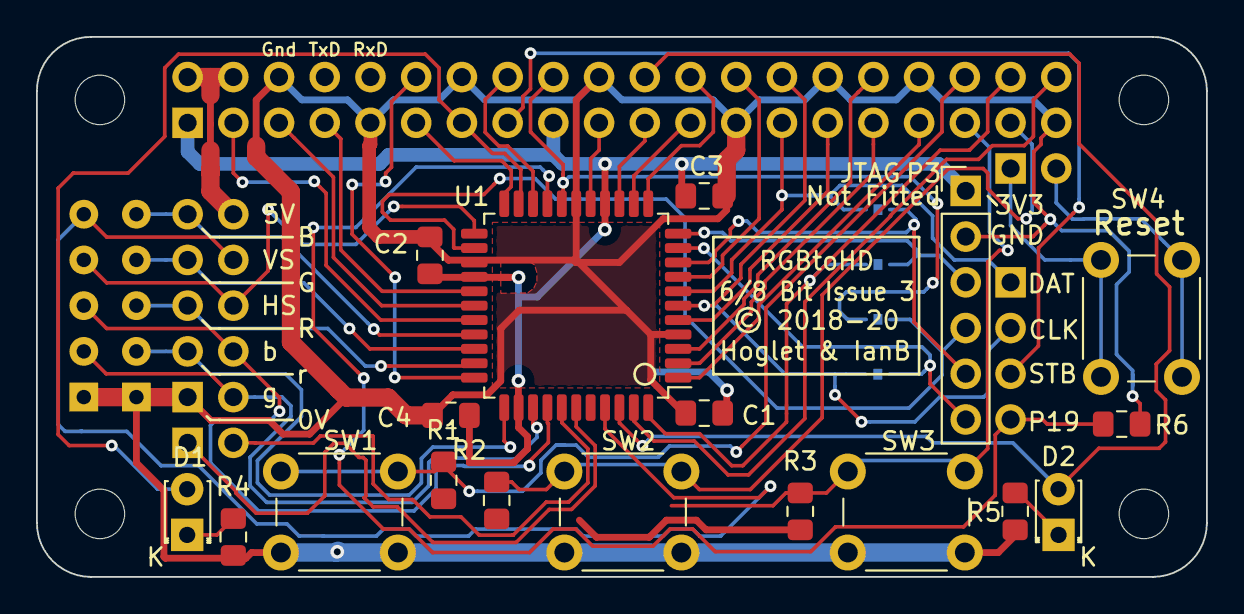
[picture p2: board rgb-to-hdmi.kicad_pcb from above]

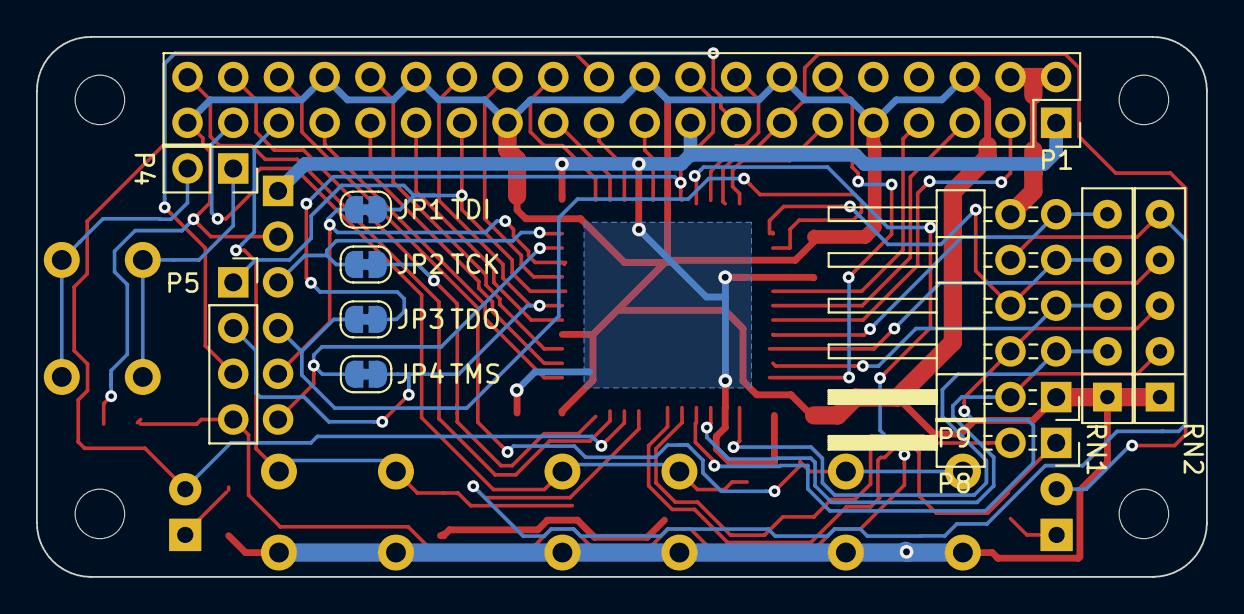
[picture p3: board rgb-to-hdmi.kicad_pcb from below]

Board: 2 copper layers, 65.0 x 30.0 mm, 29 parts (11 on the bottom side), 48 nets.

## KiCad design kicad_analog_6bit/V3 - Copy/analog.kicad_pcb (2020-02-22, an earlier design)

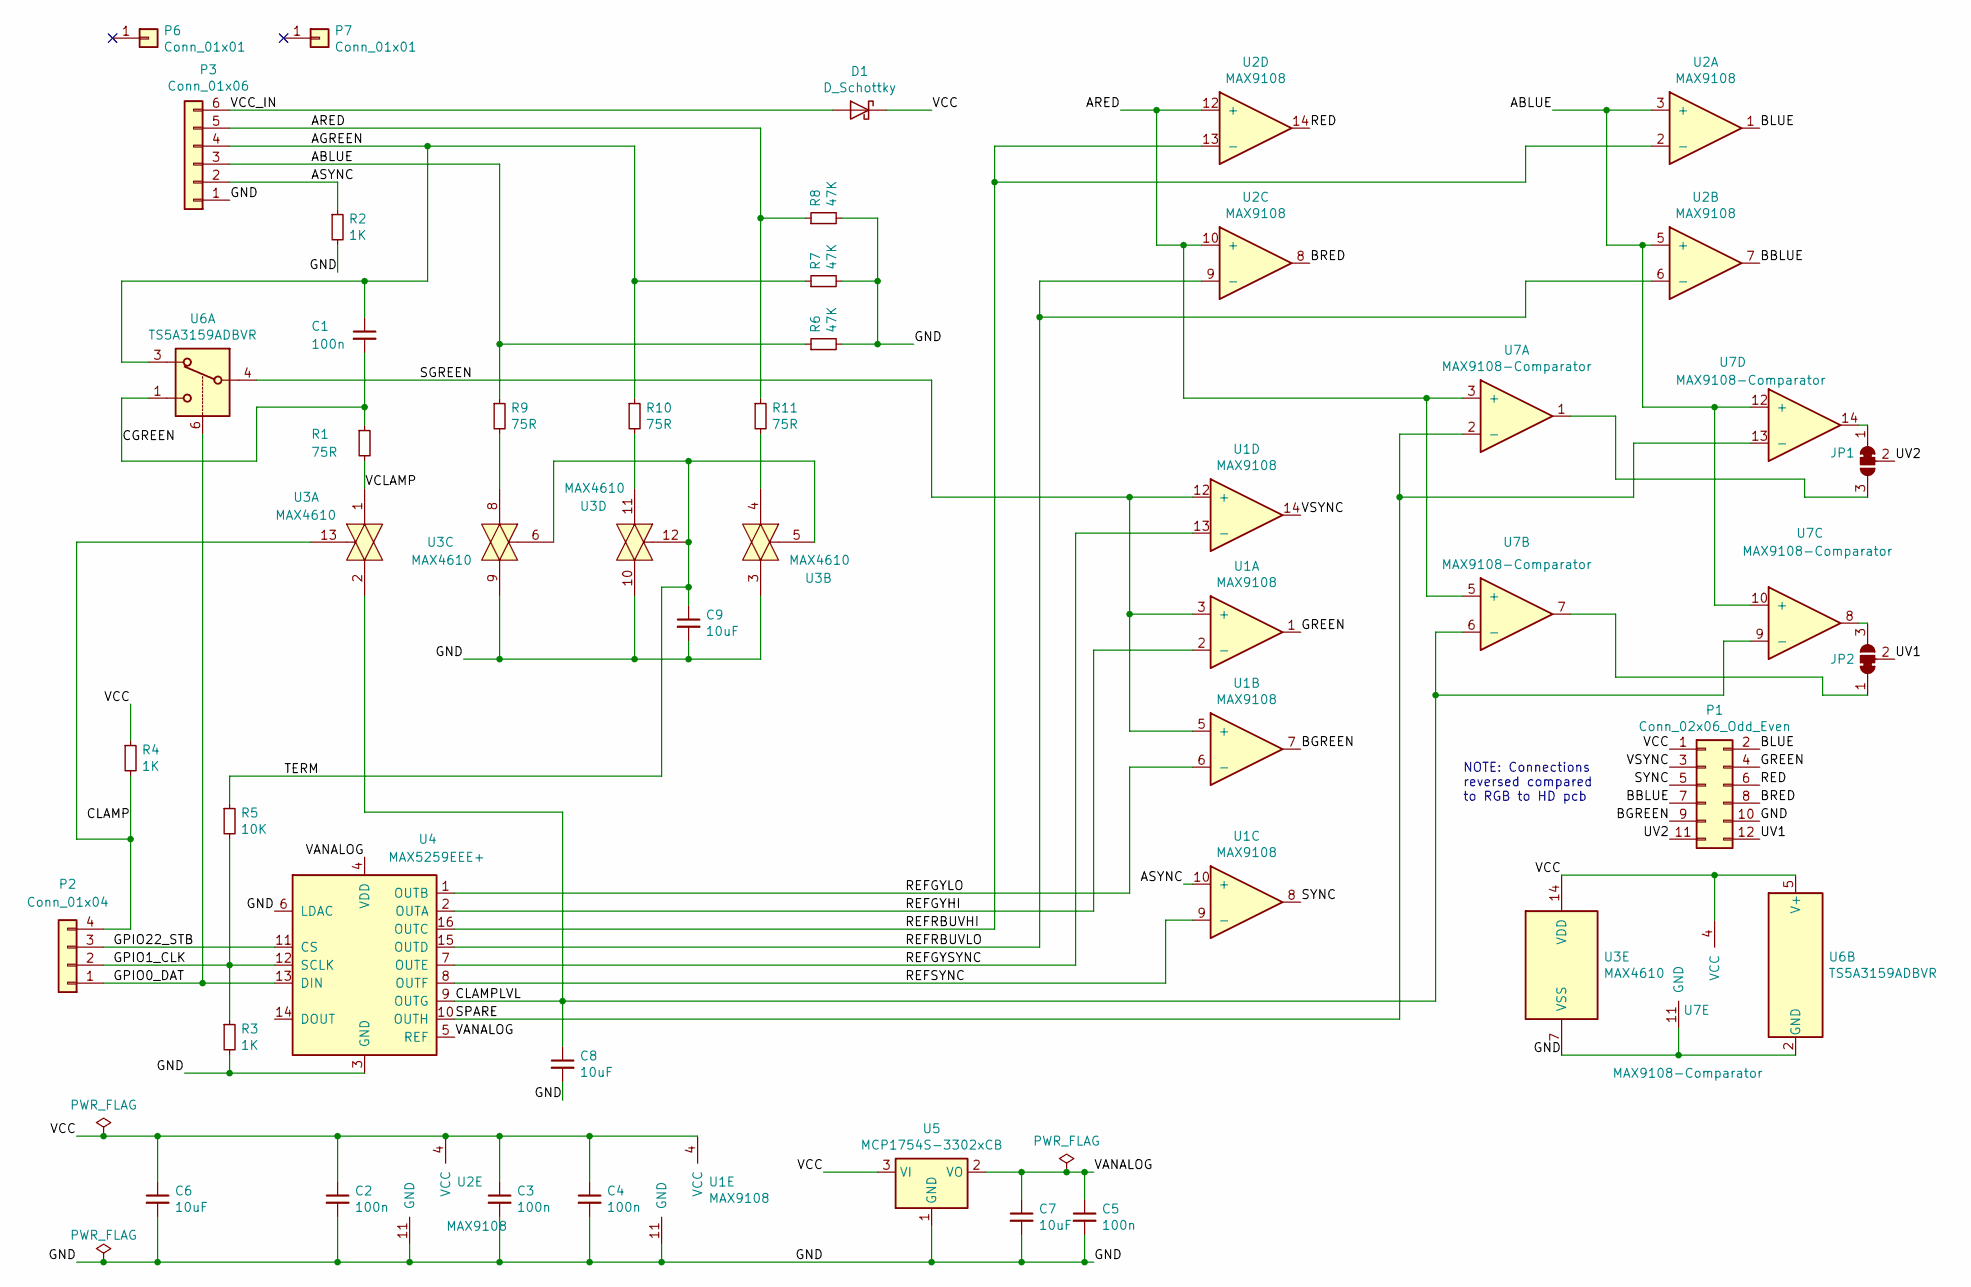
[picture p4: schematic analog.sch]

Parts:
C1, C2, C3, C4, C5: 100n; C_0805_2012Metric_Pad1.15x1.40mm_HandSolder
C6, C7, C8, C9: 10uF; C_0805_2012Metric_Pad1.15x1.40mm_HandSolder
D1: D_Schottky; D_0805_2012Metric_Pad1.15x1.40mm_HandSolder
JP1, JP2: SolderJumper_3_Bridged12; SolderJumper-3_P1.3mm_Bridged12_RoundedPad1.0x1.5mm
P1: Conn_02x06_Odd_Even; PinSocket_2x06_P2.54mm_Horizontal
P2: Conn_01x04; PinHeader_1x04_P2.54mm_Vertical
P3: Conn_01x06; Molex_PicoBlade_53048-0610_1x06_P1.25mm_Horizontal
P6, P7: Conn_01x01; PinHeader_1x01_P2.54mm_Vertical
R1, R9, R10, R11: 75R; R_0805_2012Metric_Pad1.15x1.40mm_HandSolder
R2, R3, R4: 1K; R_0805_2012Metric_Pad1.15x1.40mm_HandSolder
R5: 10K; R_0805_2012Metric_Pad1.15x1.40mm_HandSolder
R6, R7, R8: 47K; R_0805_2012Metric_Pad1.15x1.40mm_HandSolder
U1, U2: MAX9108; SOIC-14_3.9x8.7mm_P1.27mm
U3: MAX4610; SOIC-14_3.9x8.7mm_P1.27mm
U4: MAX5259EEE+; QSOP-16_3.9x4.9mm_P0.635mm
U5: MCP1754S-3302xCB; SOT-23_Handsoldering
U6: TS5A3159ADBVR; SOT-23-6_Handsoldering
U7: MAX9108-Comparator; SOIC-14_3.9x8.7mm_P1.27mm

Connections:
/ABLUE: P3.3, R6.1, R9.1, U2.3 (+), U2.5 (+), U7.10 (+), U7.12 (+)
/AGREEN: C1.1, P3.4, R7.1, R10.1, U6.3
/ARED: P3.5, R8.1, R11.1, U2.10 (+), U2.12 (+), U7.3 (+), U7.5 (+)
/ASYNC: P3.2, R2.1, U1.10 (+)
/BBLUE: P1.7, U2.7
/BGREEN: P1.9, U1.7
/BLUE: P1.2, U2.1
/BRED: P1.8, U2.8
/CGREEN: C1.2, R1.1, U6.1
/CLAMP: P2.4, R4.2, U3.13
/CLAMPLVL: C8.1, U3.2, U4.9 (OUTG), U7.6 (-), U7.9 (-)
/GND: C2.2, C3.2, C4.2, C5.2, C6.2, C7.2, C8.2, C9.2, P1.10, P3.1, R2.2, R3.2, R6.2, R7.2, R8.2, U1.11 (GND), U2.11 (GND), U3.3, U3.7 (VSS), U3.9, U3.10, U4.3 (GND), U4.6 (LDAC), U5.1 (GND), U6.2 (GND), U7.11 (GND)
/GPIO0_DAT: P2.1, U4.13 (DIN), U6.6
/GPIO1_CLK: P2.2, R3.1, R5.2, U4.12 (SCLK)
/GPIO22_STB: P2.3, U4.11 (CS)
/GREEN: P1.4, U1.1
/RED: P1.6, U2.14
/REFGYHI: U1.2 (-), U4.2 (OUTA)
/REFGYLO: U1.6 (-), U4.1 (OUTB)
/REFGYSYNC: U1.13 (-), U4.7 (OUTE)
/REFRBUVHI: U2.2 (-), U2.13 (-), U4.16 (OUTC)
/REFRBUVLO: U2.6 (-), U2.9 (-), U4.15 (OUTD)
/REFSYNC: U1.9 (-), U4.8 (OUTF)
/SGREEN: U1.3 (+), U1.5 (+), U1.12 (+), U6.4
/SPARE: U4.10 (OUTH), U7.2 (-), U7.13 (-)
/SYNC: P1.5, U1.8
/TERM: C9.1, R5.1, U3.5, U3.6, U3.12
/UV1: JP2.2 (C), P1.12
/UV2: JP1.2 (C), P1.11
/VANALOG: C5.1, C7.1, U4.4 (VDD), U4.5 (REF), U5.2 (VO)
/VCC: C2.1, C3.1, C4.1, C6.1, D1.1 (K), P1.1, R4.1, U1.4 (VCC), U2.4 (VCC), U3.14 (VDD), U5.3 (VI), U6.5 (V+), U7.4 (VCC)
/VCC_IN: D1.2 (A), P3.6
/VCLAMP: R1.2, U3.1
/VSYNC: P1.3, U1.14
unnamed: JP1.1 (A), U7.14
unnamed: JP1.3 (B), U7.1
unnamed: JP2.1 (A), U7.7
unnamed: JP2.3 (B), U7.8
unnamed: R9.2, U3.8
unnamed: R10.2, U3.11
unnamed: R11.2, U3.4

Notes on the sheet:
NOTE: Connections reversed compared to RGB to HD pcb

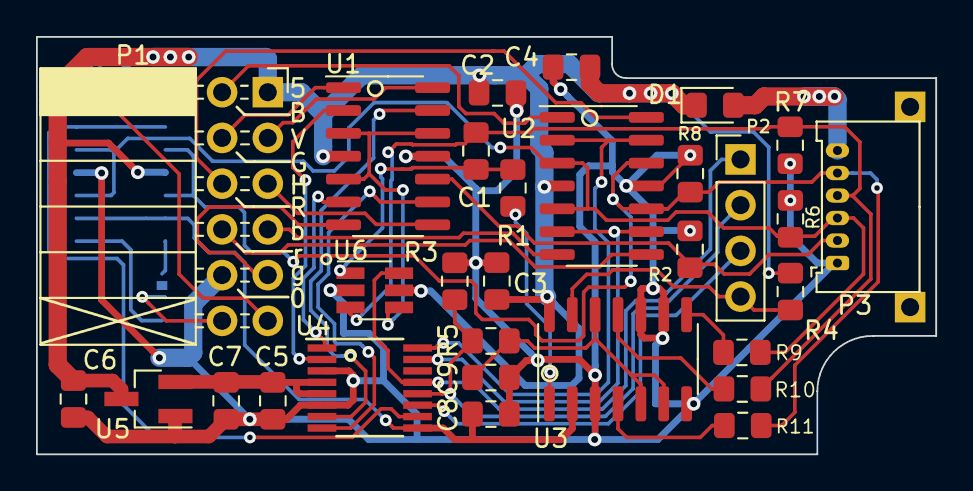
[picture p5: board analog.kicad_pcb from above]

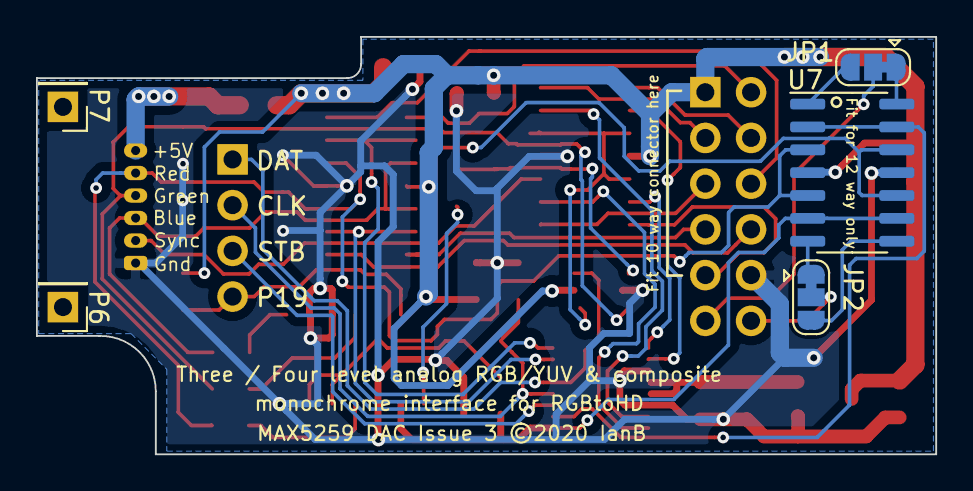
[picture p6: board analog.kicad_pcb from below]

Board: 2 copper layers, 50.0 x 23.2 mm, 35 parts (5 on the bottom side), 41 nets.

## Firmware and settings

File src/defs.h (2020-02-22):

// defs.h

#ifndef DEFS_H
#define DEFS_H

// Define how the Pi Framebuffer is initialized
// - if defined, use the property interface (Channel 8)
// - if not defined, use to the the framebuffer interface (Channel 1)
//
// Note: there seem to be some weird caching issues with the property interface
// so using the dedicated framebuffer interface is preferred.
// but that doesn't work on the Pi3
#define USE_PROPERTY_INTERFACE_FOR_FB

// Define the legal range of HDMI pixel clocks
#define MIN_PIXEL_CLOCK      25.0 //  25MHz
#define MAX_PIXEL_CLOCK     165.0 // 165MHz
#define MAX_PIXEL_CLOCK_260 260.0 // 260MHz

// Enable multiple buffering and vsync based page flipping
#define MULTI_BUFFER

// The maximum number of buffers used by multi-buffering
// (it can be set to less that this on the OSD)
#define NBUFFERS 4

#define VSYNCINT 16

// Control bits (maintained in r3)

#define BIT_MODE7          0x01       // bit  0, indicates mode 7
#define BIT_PROBE          0x02       // bit  1, indicates the mode is being determined
#define BIT_CALIBRATE      0x04       // bit  2, indicates calibration is happening
#define BIT_OSD            0x08       // bit  3, indicates the OSD is visible
#define BIT_MODE_DETECT    0x10       // bit  4, indicates mode changes should be detected
#define BIT_NO_LINE_DOUBLE 0x20       // bit  5, if set then lines aren't duplicated in capture
#define BIT_NO_SCANLINES   0x40       // bit  6, indicates scan lines should be made visible
#define BIT_FIELD_TYPE     0x80       // bit  7, indicates the field type (0 = odd, 1 = even) of the last field
#define BIT_CLEAR         0x100       // bit  8, indicates the frame buffer should be cleared
#define BIT_VSYNC         0x200       // bit  9, indicates the red vsync indicator should be displayed
#define BIT_VSYNC_MARKER  0x400       // bit 10, indicates current line should be replaced by the red vsync indicator
#define BIT_DEBUG         0x800       // bit 11, indicates the debug grid should be displayed

#define OFFSET_LAST_BUFFER 12        // bit 12-13 LAST_BUFFER
#define MASK_LAST_BUFFER (3 << OFFSET_LAST_BUFFER)

#define OFFSET_CURR_BUFFER 14        // bit 14-15 CURR_BUFFER
#define MASK_CURR_BUFFER (3 << OFFSET_CURR_BUFFER)

#define OFFSETDUP_PALETTE_HIGH_NIBBLE 12        // bit 12-15
#define MASKDUP_PALETTE_HIGH_NIBBLE (15 << OFFSETDUP_PALETTE_HIGH_NIBBLE)

#define BIT_INTERLACED 0x10000       // bit 16, indicates the frame is expected to be interlaced
#define BIT_PSYNC_POL  0x20000       // bit 17, indicates psync inversion (NEEDS TO MATCH PSYNC_PIN below)

#define OFFSET_NBUFFERS    18        // bit 18-19 NBUFFERS
#define MASK_NBUFFERS    (3 << OFFSET_NBUFFERS)

#define OFFSET_INTERLACE   20        // bit 20-22 INTERLACE
#define MASK_INTERLACE   (7 << OFFSET_INTERLACE)

#define BIT_FIELD_TYPE1          0x00800000  // bit 23, indicates the field type of the previous field
#define BIT_FIELD_TYPE1_VALID    0x01000000  // bit 24, indicates FIELD_TYPE1 is valid

#define BITDUP_MODE2_16COLOUR    0x00800000  // bit 23, if set then 16 colour mode 2 is emulated by decoding mode 0

#define BIT_OLD_FIRMWARE_SUPPORT 0x02000000  // bit 25, indicates old CPLD v1 or v2
                                             // then a second time to capture stable data. The v3 CPLD delays PSYNC a
                                             // couple of cycles, so the read that sees the edge will always capture
                                             // stable data. The second read is skipped in this case.
#define BIT_NO_H_SCROLL          0x04000000  // bit 26, if set then smooth H scrolling disabled
#define BIT_ELK                  0x08000000  // bit 27, indicates we are an Electron
#define BIT_NO_AUTOSWITCH        0x10000000  // bit 28, if set then autoselect enabled
#define BIT_TELETEXT             0x20000000  // bit 29, if set then teletext enabled
#define BIT_NO_SKIP_HSYNC        0x40000000  // bit 30  clear if hsync is ignored (used by cache preload)
#define BIT_INHIBIT_MODE_DETECT  0x80000000  // bit 31  inhibit mode detection if sideways scrolling

// R0 return value bits
#define RET_SW1                 0x02
#define RET_SW2                 0x04
#define RET_SW3                 0x08
#define RET_EXPIRED             0x10
#define RET_INTERLACE_CHANGED   0x20
#define RET_SYNC_TIMING_CHANGED 0x40
#define RET_VSYNC_POLARITY_CHANGED 0x80
//paletteFlags
#define BIT_IN_BAND_ENABLE    0x01  // bit 0, if set in band data detection is enabled
#define BIT_IN_BAND_DETECTED  0x02  // bit 1, if set if in band data is detected
#define BIT_MODE2_PALETTE     0x04  // bit 2, if set mode 2 palette is customised
#define BIT_MODE7_PALETTE     0x08  // bit 3, if set mode 7 palette is customised
#define BIT_SET_MODE2_16COLOUR   0x10  // bit 4, if set mode 2 16 colour is enabled
#define BIT_MULTI_PALETTE        0x020   // bit 5  if set then multiple 16 colour palettes

#define VERTICAL_OFFSET         6      // start of actual bbc screen from start of buffer
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

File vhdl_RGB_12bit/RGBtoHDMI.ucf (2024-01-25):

# Global Clock Nets
NET "clk" BUFG=CLK;

# 96MHz clock domain
NET "clk" TNM_NET = clk_period_grp_1;
TIMESPEC TS_clk_period_1 = PERIOD "clk_period_grp_1" 5.2ns HIGH;


NET "clk"       LOC = "P43";       # input  gpio21 (gclk)

NET "R3_I"      LOC = "P32";       # input
NET "G3_I"      LOC = "P31";       # input
NET "B3_I"      LOC = "P30";       # input
NET "R2_I"      LOC = "P34";       # input
NET "G2_I"      LOC = "P36";       # input
NET "B2_I"      LOC = "P37";       # input
NET "R1_I"      LOC = "P39";       # input  (was gpio26)
NET "G1_I"      LOC = "P40";       # input  (was gpio19)
NET "B1_I"      LOC = "P38";       # input  (was gpio16)
NET "R0_I"      LOC = "P21";       # input  (was gpio27)
NET "G0_I"      LOC = "P42";       # input  (was gpio25)
NET "B0_I"      LOC = "P18";       # input  (was gpio24)

NET "csync_I"   LOC = "P23";       # input
NET "vsync_I"   LOC = "P41";       # input  (connects to vsync)

NET "analog"    LOC = "P19";       # input  gpio22

NET "version"   LOC = "P33";       # input  gpio18 (gsr)

NET "sp_clken"  LOC = "P6";        # input  gpio1  (input only)

NET "quad(0)"   LOC = "P29";       # output gpio2
NET "quad(1)"   LOC = "P28";       # output gpio3
NET "quad(2)"   LOC = "P27";       # output gpio4
NET "quad(3)"   LOC = "P5";        # output gpio5
NET "quad(4)"   LOC = "P2";        # output gpio6
NET "quad(5)"   LOC = "P8";        # output gpio7
NET "quad(6)"   LOC = "P12";       # output gpio8
NET "quad(7)"   LOC = "P14";       # output gpio9
NET "quad(8)"   LOC = "P16";       # output gpio10
NET "quad(9)"   LOC = "P13";       # output gpio11
NET "quad(10)"  LOC = "P3";        # output gpio12
NET "quad(11)"  LOC = "P1";        # output gpio13

NET "psync"     LOC = "P22";       # output gpio17
NET "csync"     LOC = "P20";       # output gpio23

NET "quad(0)"   SLOW;
NET "quad(1)"   SLOW;
NET "quad(2)"   SLOW;
NET "quad(3)"   SLOW;
NET "quad(4)"   SLOW;
NET "quad(5)"   SLOW;
NET "quad(6)"   SLOW;
NET "quad(7)"   SLOW;
NET "quad(8)"   SLOW;
NET "quad(9)"   SLOW;
NET "quad(10)"  SLOW;
NET "quad(11)"  SLOW;
NET "psync"     SLOW;
NET "csync"     SLOW;

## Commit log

2020-02-16 Experimental V3 analog layout using GPIOs 0 & 1 to control termination
    [analog.kicad_pcb, analog.sch]
2020-02-16 Support inverted termination including CPLD programming
    [defs.h, ports.c]
2020-02-16 Update issue 3 with normally closed DG441
    [analog.kicad_pcb, analog.sch]
2020-02-17 Analog V3 non-inverted 14 pin
    [analog.kicad_pcb, analog.sch]
2020-02-18 V3 PCB layout with MAX4610
    [analog.kicad_pcb, analog.sch]
2020-02-18 Change CPLD programming to have an average voltage below the logic 0 threshold
2020-02-19 Update pcb with AC/DC switch
    [analog.kicad_pcb, analog.sch]
2020-02-21 V3 pcb plus some older alternatives
    [analog.kicad_pcb, analog.sch]
2020-02-21 Tweaks to V3 analog PCB
    [analog.kicad_pcb]
2020-02-22 Updated analog board
    [analog.kicad_pcb, analog.sch]
2020-02-22 Updated 8 bit
    [analog.kicad_pcb, analog.sch]
2020-02-22 Updated 8 bit hat
    [rgb-to-hdmi-B_Cu.gbl, rgb-to-hdmi-B_Mask.gbs, rgb-to-hdmi-B_SilkS.gbo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]
2020-02-22 Update profiles for ac/dc coupling
2020-02-22 Update ac/dc switch and analog driver

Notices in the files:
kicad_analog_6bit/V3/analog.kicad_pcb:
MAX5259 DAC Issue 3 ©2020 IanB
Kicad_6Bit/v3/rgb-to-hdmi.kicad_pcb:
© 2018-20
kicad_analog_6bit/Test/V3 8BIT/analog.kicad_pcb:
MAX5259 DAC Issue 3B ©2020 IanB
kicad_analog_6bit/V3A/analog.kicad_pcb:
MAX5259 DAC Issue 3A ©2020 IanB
